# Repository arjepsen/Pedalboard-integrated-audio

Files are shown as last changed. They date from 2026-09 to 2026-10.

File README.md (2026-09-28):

# Open Guitar Processing Platform.

A custom Raspberry Pi Compute Module 5 guitar-processing platform with integrated low-latency audio and a separate ESP32-S3 user-interface board.

<p align="center">
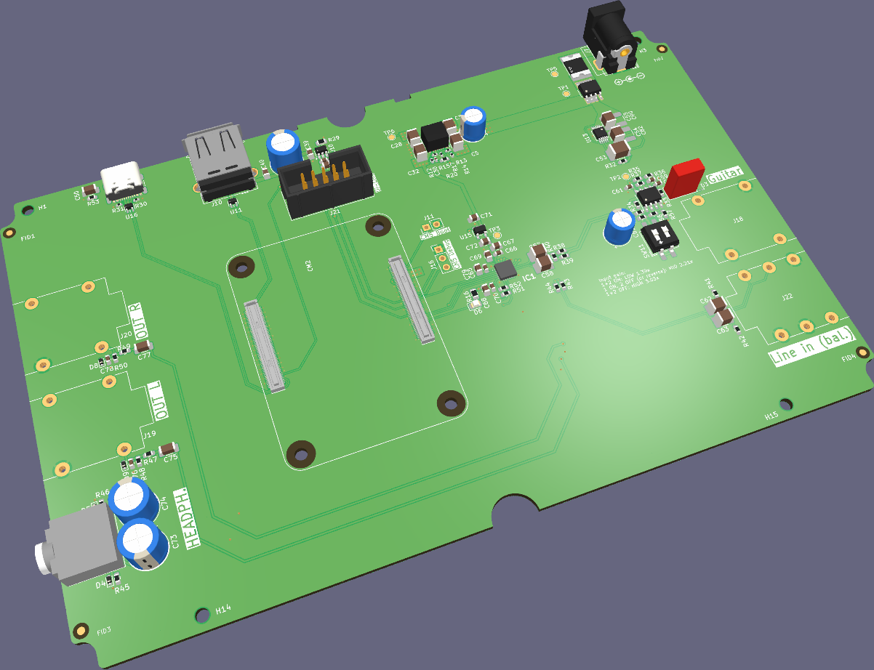
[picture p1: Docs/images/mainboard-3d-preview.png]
3D render of the mainboard
  
</p>

The project is derived from various other similar projects:
https://github.com/pedalboard
https://rerdavies.github.io/pipedal/
https://www.treefallsound.com/

The hardware has been substantially redesigned around an integrated TAC5212 audio codec, CM5, and a separate UI controller.

The primary software target is the **pi-Stomp / MOD** stack. **PiPedal** is intended as an alternative audio environment using the same hardware.

## Design goals

The main priorities are:

1. Low audio latency
2. High audio quality and low noise
3. Simple hardware where additional complexity provides no meaningful benefit
4. Clean separation of switching, digital, and sensitive analog circuitry
5. Practical manufacture and assembly through JLCPCB
6. Straightforward hand assembly of parts that are impractical or unnecessarily expensive to have assembled

## System architecture

The system is split between two PCBs.

### Mainboard

The mainboard contains the complete audio and compute system:

- Raspberry Pi Compute Module 5
- TAC5212 stereo audio codec
- OPA1656 high-impedance guitar input front end
- Balanced line input
- Dedicated stereo headphone output
- Stereo line/amp output
- TLVM13660 main 5 V power supply
- Low-noise analog power supply
- Codec power supplies
- USB service/recovery connection
- External USB host connection
- Power and UART connection to the UI board

The mainboard is a **four-layer PCB**.

### UI board

The physical controls and display are moved to a separate PCB based on:

- ESP32-S3-WROOM-1U-N8R2
- 3.5-inch SPI TFT display
- Four rotary encoders with push switches
- Four footswitch inputs
- One expression-pedal input
- Up to four indicator LEDs
- Optional chassis-wired MIDI input/output
- Local 3.3 V power supply

The UI board receives 5 V from the mainboard.

Communication between the CM5 and ESP32-S3 uses **UART**. There is no USB connection between the CM5 and UI controller.

The CM5 can also control ESP32-S3 reset and boot mode through the UI interconnect.

## Software architecture

### Primary environment

The primary target is the **pi-Stomp** software environment using:

- MOD-UI
- mod-host
- JACK
- LV2 plugins
- Neural Amp Modeler compatible processing

The intention is to retain the useful pi-Stomp interaction model while adapting it to the custom hardware.

### Alternative environment

**PiPedal** is intended to run as an alternative software environment on the same hardware.

MOD and PiPedal are not intended to operate simultaneously. The system will select which audio environment is active.

### Division of responsibilities

The **CM5** handles:

- Audio processing
- Plugin hosting
- Audio-engine control
- Presets and pedalboards
- System state
- Parameter state
- Communication with the TAC5212
- Communication with the UI controller

The **ESP32-S3** handles:

- Display rendering
- Rotary encoders
- Encoder push switches
- Footswitches
- Expression-pedal sampling
- Indicator LEDs
- Optional future MIDI handling
- Sending user commands to the CM5

The CM5 sends state changes to the ESP32-S3 rather than rendering the user interface (The display) itself.

## Audio architecture

The audio system is built around the **TI TAC5212** codec.

The normal operating point is:

- 48 kHz sample rate
- Stereo I2S
- 32-bit slots
- CM5 as I2S clock producer
- TAC5212 as clock consumer
- No separate audio master-clock oscillator
- Low-latency TAC5212 ADC and DAC filter modes

### Guitar input

Input channel 1 is intended for passive electric guitar pickups.

An **OPA1656** provides the high-impedance input stage and converts the guitar signal to the differential signal required by the TAC5212.

The design provides approximately 1 MΩ guitar input impedance and includes selectable input gain.

The codec input is AC-coupled.

### Line input

Input channel 2 provides a balanced line-level input.

It is AC-coupled into the second differential TAC5212 ADC input.

### Outputs

The system provides:

- Dedicated stereo headphone output
- Stereo unbalanced line/amp output

The TAC5212's output capabilities are used directly where practical in order to avoid unnecessary additional analog stages.

## Power architecture

The board accepts an external DC supply and generates the required system rails locally.

The main power path consists of:

1. Input protection
2. Reverse-polarity protection
3. TLVM13660 switching regulator
4. Main 5 V system rail

The 5 V rail supplies the CM5 and the downstream power systems.

Separate low-noise supplies are used where appropriate for sensitive analog and codec circuitry.

The analog guitar front end uses a quiet higher-voltage rail to provide adequate signal headroom.

The UI board receives 5 V from the mainboard and generates its own local 3.3 V supply.

Power-supply layout, switching-current loops, grounding, thermal performance, and separation from the analog signal path are treated as critical PCB-layout requirements.

## Mainboard / UI connection

The mainboard and UI board use a keyed 10-pin connection carrying:

| Signal | Function |
|---|---|
| +5V_UI | UI-board power |
| GND | Power/signal return |
| CM5_UART_TX | CM5 to ESP32-S3 data |
| CM5_UART_RX | ESP32-S3 to CM5 data |
| UI_RESET_REQ | ESP32-S3 reset request |
| UI_BOOT_REQ | ESP32-S3 boot-mode request |

Multiple 5 V and ground contacts are used in the connector.

The connection is intended to use a short ribbon cable between the two boards.

## USB

USB is kept separate from the UI-controller connection.

The CM5 provides a USB service connection for functions including:

- CM5 recovery / eMMC flashing
- Wired system access
- USB networking

An external USB host connection is also retained.

The ESP32-S3 UI board does not require a USB connection to the CM5.

## MIDI

MIDI is not required for the initial build.

The UI design is intended to preserve the possibility of adding MIDI later without requiring another mainboard revision.

If implemented, MIDI connectors will be chassis-mounted and wired to dedicated connection points on the UI board, rather than placing large DIN/TRS connectors directly on the PCB.

## Mechanical design

The system is intended for installation in an aluminium pedal enclosure.

The mainboard carries the CM5 and audio electronics.

The separate UI board sits beneath the top panel and carries the display, footswitches and rotary controls.

The design must provide sufficient cooling for the CM5. A heatsink and fan are expected, with enclosure ventilation provided as necessary.

The use of a separate UI PCB reduces congestion around the CM5 and allows the display and controls to be positioned according to the enclosure rather than the mainboard layout.

## PCB design

The mainboard uses a **four-layer stackup**.

Important layout priorities include:

- Continuous low-impedance ground
- Small switching-regulator current loops
- Correct TLVM13660 thermal layout
- Separation of the switching supply from sensitive audio circuitry
- Short codec analog paths
- Short local decoupling connections
- Controlled digital return paths
- Sensible separation of CM5, power, codec, and analog regions
- Appropriate USB differential routing
- Good thermal paths for the CM5 and power supply

The PCB is intended for manufacture and partial assembly by **JLCPCB**.

Where performance is equivalent, readily available and economical assembly parts are preferred. More expensive or manually fitted components are used where they provide a meaningful electrical, mechanical, or sourcing advantage.

## Current status

The project is currently in the mainboard PCB-layout stage.

The major mainboard architecture and audio topology have been established.

Current work includes:

- Component placement and floorplanning
- TLVM13660 routing and thermal-via implementation
- Power-distribution layout
- Analog/digital partitioning
- Ground and return-current planning
- Final verification of the mainboard before manufacture

The separate ESP32-S3 UI PCB will be designed after the mainboard architecture and mechanical relationship between the two boards are sufficiently settled.

Because this is intended as a one-off build rather than an iterative prototype programme, schematic and PCB decisions are being reviewed carefully before manufacture.

## Repository structure

The main KiCad project contains the CM5, audio, power, and external-connectivity hardware.

Important documentation is kept under `Docs/`, including:

- `project-status.md` — current project state
- `decisions.md` — established design decisions and their reasoning
- `design-notes.md` — detailed engineering notes
- `work-log.md` — chronological record of completed work
- `mainboard-ui-transition-plan.md` — transition from the former integrated controller to the separate ESP32-S3 UI architecture

The UI PCB is intended to remain part of this repository as a separate KiCad project so that the two boards, their interconnect, and their firmware interface can be versioned together.

## Project history

This project began as a modification of the Open Pedalboard hardware.

The design has since moved substantially beyond the original architecture, including:

- CM5-only compute platform
- Integrated TAC5212 audio codec
- Custom high-impedance guitar front end
- Revised audio outputs
- Revised power architecture
- Four-layer PCB
- TLVM13660 main supply
- Separate ESP32-S3 UI controller
- UART-based CM5/UI communication
- pi-Stomp/MOD as the primary software direction

The original Open Pedalboard project remains an important hardware and software reference.

## License

This project is derived from Open Pedalboard hardware.

See the repository license files and the original Open Pedalboard project for applicable licensing information.

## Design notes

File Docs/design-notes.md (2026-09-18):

# Design Notes

Last updated: 2026-09-17

## Audio architecture

- Selected codec: TAC5212IRGER, mounted directly on the mainboard.
- Primary use: guitar effects and NAM playback using Open Pedalboard or PiPedal software. Must be compatible with both.
- Input 1 is a high-impedance guitar input.
- Input 2 is an optional balanced line input.
- Both codec inputs are differential and AC-coupled.
- The CM connection uses I2S/PCM audio signals plus I2C control.
- Main audio operating point: 48 kHz sample rate, stereo I2S with 32-bit slots.
- CM5 is the I2S clock producer; TAC5212 follows BCLK and FSYNC and derives its internal clocks from that interface. No separate MCLK oscillator is required.
- Use the TAC5212 ultra-low-latency ADC and DAC filters for the main guitar path.

The TAC5212 combines the required stereo ADC and DAC. Its differential AC-coupled mode offers its best input performance, while programmable input impedance and full-scale settings allow the two analog paths to be adapted in software.

## Guitar input

The first OPA1656 half is a non-inverting guitar buffer with switchable gain. The second produces an equal, inverted signal for the differential ADC input. SW11 provides three useful gain settings without an invalid switch combination.

| Part | Purpose and reason |
|---|---|
| C56: 100 nF film, MKS2 footprint | Main input coupling capacitor; film construction suits the high-impedance signal node |
| C64: 100 nF C0G, 1206, DNP | Optional SMD alternative to C56; fit only one of the two capacitors |
| R33: 1 MΩ | Defines normal guitar input impedance and biases the buffer at 4 V |
| R34/R37: 1 kΩ | Equal values set the second amplifier to an inverting gain of -1 |
| R38/R39: 470 Ω and R40: 1 kΩ | Isolate the op-amp outputs and form a balanced divider that gives approximately 1x overall differential gain |
| R54/R56: 820 Ω, R55: 390 Ω, R57: 1 kΩ | Set the selectable non-inverting gains to approximately 1.39×, 2.21×, and 3.03× |
| SW11: EM-02-Q | Independently bypasses R54 and R56; either single-switch position gives the same middle gain |
| C57/C58: 4.7 µF Rubycon MF | Low-voltage-coefficient coupling into TAC5212 input 1 |
| D3: H5VUD5BB, DNP | Protection placeholder; not fitted until its capacitance and behavior are accepted |

C56 and R33 form a high-pass corner of about 1.6 Hz. The high-impedance node after C56 should be kept short and away from digital and switching signals.

The OPA1656 was chosen for its FET inputs, very low input bias current, low noise and distortion, and ability to operate from the 10 V single supply.

The selected TAC5212 range is 2 V RMS differential. Approximate guitar-jack clipping levels are 2.0 V peak on low gain, 1.3 V peak on middle gain, and 0.94 V peak on high gain.

## Line input

J22 is a balanced TRS line input. A TS plug remains usable because the ring is grounded by the plug.

| Part | Purpose and reason |
|---|---|
| R41/R42: 100 kΩ | Give both jack signal contacts a defined ground reference, provide balanced loading, and discharge the coupling capacitors |
| C62/C63: 4.7 µF Rubycon MF | AC-couple both balanced legs with a corner safely below the audio band |
| R43/R44: 7.5 kΩ | Provide equal series impedance, fault-current limiting, and line-level attenuation before the codec |

With the TAC5212 set to 5 kΩ input impedance, each 7.5 kΩ resistor gives approximately 0.4x voltage transfer. This corresponds to about 5 V RMS differential at J22 for the codec's 2 V RMS differential full scale.

The former JP4 connection from the jack switch to CM GPIO27 has been removed. The software does not use this automatic stereo-detection signal, and GPIO27 is intentionally unconnected.

## TAC5212 configuration assumptions

- Differential, AC-coupled input mode for both ADC channels.
- Main operating rate: 48 kHz.
- Stereo I2S with 32-bit slots; BCLK is 3.072 MHz at 48 kHz.
- CM5 produces BCLK and FSYNC; TAC5212 is the clock consumer.
- No dedicated audio master-clock oscillator is required.
- Use ultra-low-latency ADC and DAC filters for the main low-latency path.
- Set input-capacitor quick-charge timing to 25 ms for the 4.7 µF coupling capacitors.
- Use 5 kΩ per input pin, 2 V RMS differential full scale, and 0 dB initial codec gain on both ADC channels.
- Use the low-common-mode-variation AC-coupled setting for best noise performance.
- Final Linux register configuration and practical bring-up still require verification.

### TAC5212 local decoupling

- AVDD: C66 100 nF + C67 10 µF.
- IOVDD: C70 100 nF + C68 10 µF.
- DREG: C65 100 nF + C79 10 µF.
- VREF: C69 1 µF.
- C79 uses Samsung CL21A106KAYNNNE, 10 µF, 25 V, X5R, 0805, LCSC C15850.
- Place the DREG capacitors physically close to TAC5212 pin 1 during layout.

## Audio outputs

- Use the TAC5212 in four-channel single-ended output mode.
- Two outputs provide a dedicated stereo headphone connection on a 3.5 mm TRS jack.
- Two outputs provide left and right unbalanced line/amp signals on the existing 6.35 mm jacks.
- Configure the headphone pins for headphone drive and the 6.35 mm pins for line drive.
- Route the same stereo program to both output pairs using the TAC5212 playback mixer.
- Retain normal TS-cable compatibility; balanced outputs are not a present requirement.

This arrangement matches the primary desk-practice use without adding a separate headphone-amplifier IC. The single-ended line outputs give lower specified dynamic range than differential mode, but remain well above the expected system requirement. Final register settings and practical testing remain open.

## Power architecture

- Specify a regulated 12 V input with ±10% tolerance.
- Retain the 4 A / 15 V input PTC and FDS4435BZ reverse-polarity protection.
- Generate approximately 5.02 V with TLVM13660RDLR and its integrated inductor. R12 at 40.2 kΩ and R15 at 10 kΩ set the output. This rail supplies the CM and downstream regulators.
- Use AP22653W6-7 to switch and current-limit the external USB-A VBUS. R29 at 15 kΩ sets approximately 1.735 A typical. C39 and C40 at 10 µF plus C43 at 100 µF provide the recommended 120 µF output bank.
- Generate the general digital 3.3 V and `3V3_CODEC` analog rail with separate TPS7A2033PDBVR regulators.
- Keep C24 at 10 µF on the general 3.3 V regulator output.
- Generate the quiet 10 V guitar-front-end rail with LT3045EMSE#PBF. Use 4.7 µF on SET, 100 kΩ for 10 V, 10 µF at its input, and 22 µF at its output.
- Continue tracking total capacitance rail-by-rail together with regulator stability, soft-start, source impedance, and startup/inrush. Do not add local bulk capacitance without checking its effect on the whole rail.

The 10 V rail is retained because it gives the OPA1656 input path comfortable signal headroom. The approximately 5.02 V / 6 A supply provides useful CM5 and USB-current margin.

The general 3.3 V rail has been rechecked with the selected Waveshare displays. Each display is specified at about 46 mA maximum at 3.3 V, so the pair contributes about 92 mA. With the STM32 and the remaining small digital loads, the expected total is around 120 mA. The TPS7A2033 is rated for 300 mA, leaving comfortable current and thermal margin from the approximately 5.02 V input. C24 remains 10 µF because it is within the regulator's supported output-capacitance range and provides useful transient margin.

## Controller and displays

- U3 is an STM32G0B1CET6 in LQFP-48. It replaces the RP2040, its external QSPI flash, crystal, and associated support parts.
- Use the STM32's internal flash. No separate firmware flash is required.
- Use the internal HSI48 oscillator with USB clock recovery from the CM5 USB SOF signal. Firmware must enable CRS correctly; no external crystal is fitted.
- J15 and J17 connect to two Waveshare 2inch LCD Modules, SKU 17344. These are 2.0-inch 240×320 IPS displays using ST7789VW and 4-wire SPI.
- The modules are intended for straightforward screw/standoff mounting and use an 8-pin PH2.0 connector.
- J15 is the left display and J17 is the right display. Both use JST B8B-PH-K-S(LF)(SN) 8-pin, 2.0 mm vertical headers on the mainboard.
- The display connector pin order is BL, RESET, D/C, CS, SCK, MOSI, GND, 3V3. The shared signals are BL, RESET, D/C, SCK, and MOSI; each display has its own chip select.
- The Waveshare module includes its own 1 µF supply capacitor, so no extra local capacitor is fitted at J15/J17. The shared 3.3 V regulator retains C24 at 10 µF.
- The module contains the backlight switching transistor, so PA6 can drive both BL control inputs directly with PWM; an external backlight transistor is not required.
- Use DMA and small line/tile buffers rather than full framebuffers.
- Keep the display connectors on this controller/UI sheet. Their signals and power belong to the controller function, whereas the Connectivity sheet is for CM5 and external/service connections.
- Port the required controller behavior from the original Rust code to C/C++ while preserving its useful external USB-MIDI behavior and protocol.

### STM32 pin allocation

| Function | Pins |
|---|---|
| TFT shared SPI/control | PA5 SCK, PA7 MOSI, PA4 D/C, PB12 RESET, PA6 BL PWM |
| TFT chip selects | PB10 left, PB11 right |
| Addressable RGB LEDs | PA8 |
| Expression ADC inputs | PB0, PB1 |
| I2C | PB8 SCL, PB9 SDA |
| USB device | PA11 D−, PA12 D+ |
| SWD and reset | PA13 SWDIO, PA14 SWCLK, PF2 NRST |
| Optional DIN MIDI UART | PB6 TX, PB7 RX |
| Debug UART | PA9 TX, PA10 RX |
| Encoders | PA0–PA3, PB2, PB3 |
| Footswitches | PD0–PD3, PB4, PB5 |
| Boot/status | PC13 BOOT control, PB15 status LED |

Each expression input uses a 1 kΩ series resistor and 100 nF capacitor at the MCU. Retain the SWD/debug header and useful test points. The hierarchical `RGB_DATA` connection links U3 PA8 to the LED sheet.

### Controller EEPROM

Keep U12, the AT24CS01 EEPROM at I2C address `0x50`. The existing Open Pedalboard firmware stores active-preset state, per-preset switch state, and encoder values there. This avoids turning frequent runtime-state updates into STM32 internal-flash erase cycles. Its factory serial-number area is also useful for a stable board identity, even though the existing RP2040 firmware obtains its USB serial from the MCU flash ID instead.

## CM5-only connectivity

CM2 is now a Compute Module 5 using the `CM5IO:Raspberry-Pi-5-Compute-Module` footprint. The former FSUSB42 switch and USB2514B hub have been removed. CM5 exposes one USB 2.0 OTG connection and two native USB 3 host ports with USB 2.0 companion pairs, so the required USB 2.0 functions connect directly:

| CM5 connection | Board function |
|---|---|
| Legacy USB 2.0 OTG | USB-C CM5 service, recovery, and flashing |
| USB port 0 USB 2.0 pair | Internal STM32 USB-MIDI and firmware update |
| USB port 1 USB 2.0 pair | External USB-A host connector |

Leave the SuperSpeed pairs unused. The USB port 0 companion pair connects directly to U3; USB port 1 connects to the external USB-A connector; and the legacy USB 2.0 pair connects to the service USB-C connector. U11 and U16 provide low-capacitance data-line ESD protection.

The external USB-A power circuit follows Raspberry Pi's CM5 IO reference direction. CM5 pin 111 `VBUS_EN` directly drives the active-high AP22653 enable. R29 at 15 kΩ sets approximately 1.735 A typical current limit. C16 100 nF and C38 10 µF provide local input bypass, while C39, C40, and C43 total 120 µF on VBUS. The AP22653 also provides soft start, reverse-current protection, output discharge, current limiting, and thermal protection. Its `nFAULT` output may remain unconnected because the board does not presently need software fault reporting.

J9 is a self-powered USB-C device/service connection. R30 and R31 are 5.1 kΩ pull-downs on CC1 and CC2. Connector VBUS remains intentionally unconnected to prevent back-powering the board. SBU1 and SBU2 remain unconnected. CM5 `USB_OTG_ID` remains unconnected so its internal pull-up selects device operation, while J11 pulls `nRPIBOOT` low when recovery or eMMC flashing is required.

During PCB layout, place U11 and U16 immediately behind their connectors with short ground returns. Route each USB 2.0 pair over a continuous ground plane as a 90 Ω differential pair and avoid stubs. Place U10 input and output capacitors close to their corresponding pins.

## USB software compatibility

- Open Pedalboard uses the internal controller as a bidirectional class-compliant USB-MIDI device. It carries performance MIDI, controller configuration, state/feedback, and bootloader commands.
- Preserve the existing useful controller behaviour and custom configuration protocol in the STM32 implementation.
- Pedalboard OS currently identifies the RP2040 by its Raspberry Pi USB VID/PID and product name. The STM32 migration requires a new legitimate USB identity, stable serial number, updated udev matching, and updated bridge matching.
- The present firmware updater expects the RP2040 `RPI-RP2` mass-storage bootloader and a UF2 file. Replace this with an STM32G0B1 USB-DFU update path.
- PiPedal accepts the STM32 as a standard MIDI input and can bind it to presets, snapshots, plugin controls, hotspot control, shutdown, and reboot.
- PiPedal currently provides no MIDI output feedback. Basic operation needs no PiPedal changes, but dynamic preset names and state on the TFTs would require a future CM5 companion service.
- External USB-A remains useful for optional MIDI controllers, USB audio interfaces, and normal Linux USB peripherals.
- USB Ethernet gadget mode on the service USB-C port is a useful future option for web access, SSH, and file transfer, but is not required for the initial schematic.

## MIDI

- Preserve the original DIN MIDI input and output capability in the schematic, PCB, and STM32 pin allocation.
- The optional DIN MIDI group is marked DNP: J1–J4, J25, J26, L1–L4, R3–R5, D1, U2, C1, and C22.
- Keep the software routing options for DIN-to-USB and USB-to-DIN operation.
- Initial units can use `din_enabled: false`; the optional parts can be fitted later without revising the PCB.

The DNP state has been confirmed in the raw KiCad schematic and by exporting a BOM with DNP parts excluded.

## Manufacturing

- Primary manufacturer and assembler: JLCPCB.
- Basic parts are preferred when there is little or no disadvantage.
- Extended parts are acceptable when there is a clear benefit.
- Manual fitting is acceptable for a limited number of practical components.
- Use 0603 passives where practical.
- Fine-pitch and exposed-pad packages require suitable footprints, stencil design, and inspection.
- Write capacitor values with their unit, for example `100nF`, `1uF`, and `4.7uF`. Use compact resistor notation such as `27R`, `1k5`, and `100k`.
- Standard sourcing fields are `Manufacturer`, `Manufacturer part`, and `JLCPCB part`. Use KiCad's native footprint, datasheet, description, and DNP properties instead of duplicating them as custom fields.
- The electrical-component field audit is substantially complete. Finish exact purchasing choices for connectors and other hand-fitted mechanical parts before PCB/BOM release.
- Use a four-layer PCB with continuous reference planes. Do not attempt to preserve the original two-layer layout approach.
- Ignore gaps in reference numbering. References must be unique, not continuous.
- Remove the incomplete JLCPCB variant and create a new complete variant only after the default DNP state and schematic are frozen.

## Important project state

- `audio.kicad_sch` and `psu.kicad_sch` contain the current custom work.
- The guitar input, line input, TAC5212 support, digital-audio connections, and selected output circuits are present in the schematic.
- TAC5212 DREG now has C65 100 nF plus C79 10 µF local decoupling.
- The updated power architecture is present in the schematic.
- The STM32 controller, both Waveshare display connectors, optional DIN MIDI circuit, and direct CM5 USB arrangement are present in the schematic.
- The general 3.3 V rail has been checked with the selected displays and the TPS7A2033 is retained.
- The electrical-component value and sourcing-field audit is substantially complete; remaining gaps mainly concern mechanical or hand-fitted parts.
- The PCB has not yet been updated for the integrated audio circuit.

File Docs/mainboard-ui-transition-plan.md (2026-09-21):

# Mainboard UI Transition Plan

> This is a manual KiCad checklist. It records agreed changes but does not authorize automatic schematic edits.

**Goal:** Keep the CM5, audio, power, and external connectivity on the mainboard while moving the physical user interface to a later ESP32-S3 UI board.

**Architecture:** The CM5 remains responsible for audio, MOD, PiPedal, and system state. A separate UI board will later contain the ESP32-S3, display, encoders, switches, expression input, LEDs, and optional MIDI interface. The mainboard supplies 5 V and communicates with the UI board over UART.

**Scope:** Mainboard schematic changes only. The UI-board schematic and PCB are deliberately deferred.

## Hardware changes in short form

- Remove the STM32 controller subsystem from the active mainboard design.
- Remove the mainboard display, controls, expression, MIDI, and LED-interface circuitry that will move to the UI board.
- Add one keyed 2x5 IDC connector for UI power, UART, reset, and boot control.
- Free the CM5 USB port currently assigned to the STM32.
- Keep the existing CM5 USB-C service port and use it for both recovery flashing and USB Ethernet networking.
- Keep Wi-Fi as an option, using the CM5 wireless version and an external antenna in the aluminium enclosure.
- Keep the TAC5212, guitar input, optional line input, audio outputs, CM5, and established power supplies.
- Do not remove U5 during the controller cleanup. It still powers TAC5212 IOVDD in the present design and requires a separate power-domain decision.

## Mainboard-to-UI connector

Use a keyed and shrouded 2.54 mm IDC system.

| Item | Selection |
|---|---|
| PCB header | Würth Elektronik 61201021621 |
| Cable socket | Würth Elektronik 61201023021, with strain relief |
| Cable | 10-conductor, 28 AWG ribbon cable, approximately 100 mm |
| Assembly | Header marked DNP for JLCPCB and fitted by hand |

Pin numbering must follow the connector datasheet and footprint pin-1 mark.

| Pin | Signal | Purpose |
|---:|---|---|
| 1 | `+5V_UI` | UI power, connected to mainboard `+5VP` |
| 2 | GND | Power return |
| 3 | `+5V_UI` | Second power contact, connected to mainboard `+5VP` |
| 4 | GND | Power return |
| 5 | `CM5_UART_TX` | CM5 to ESP32-S3 |
| 6 | GND | Signal return |
| 7 | `CM5_UART_RX` | ESP32-S3 to CM5 |
| 8 | GND | Signal return |
| 9 | `UI_RESET_REQ` | CM5 requests ESP32-S3 reset |
| 10 | `UI_BOOT_REQ` | CM5 requests ESP32-S3 download mode |

`UI_RESET_REQ` and `UI_BOOT_REQ` are active-high requests. The later UI board will use local MOSFETs and pull-down resistors to pull ESP32-S3 EN and GPIO0 low. This prevents the CM5 from directly driving ESP pins across different power states.

## Mainboard schematic steps

### 1. Preserve a known baseline

- [ ] Commit and push the current schematic before beginning the transition.
- [ ] Run ERC and record the starting warning count.
- [ ] Confirm that the current PCB has not yet been updated for the new controller or audio design.

### 2. Add the UI connector on the Connectivity page

- [ ] Place a generic `Conn_02x05_Odd_Even` symbol on `connect.kicad_sch`.
- [ ] Assign the verified Würth 61201021621 footprint or import Würth's official KiCad footprint.
- [ ] Set `Value` to `UI LINK 2x5`.
- [ ] Set `Manufacturer` to `Würth Elektronik`.
- [ ] Set `Manufacturer part` to `61201021621`.
- [ ] Leave `JLCPCB part` empty.
- [ ] Mark the connector DNP.
- [ ] Add the note `Hand-fit. Mates with 61201023021 IDC socket and 10-conductor 28 AWG ribbon cable.`
- [ ] Wire pins 1 and 3 to the mainboard `+5VP` rail.
- [ ] Wire pins 2, 4, 6, and 8 to GND.
- [ ] Wire pins 5, 7, 9, and 10 according to the table above.

The mainboard does not need another UI power regulator. The UI board will receive 5 V and provide its own local 3.3 V regulation and decoupling.

### 3. Connect the CM5 control signals

- [ ] Keep `CM5_UART_TX` on CM2 pin 55, GPIO14.
- [ ] Keep `CM5_UART_RX` on CM2 pin 51, GPIO15.
- [ ] Remove the no-connect flag from CM2 pin 46, GPIO22, and label it `UI_RESET_REQ`.
- [ ] Remove the no-connect flag from CM2 pin 47, GPIO23, and label it `UI_BOOT_REQ`.
- [ ] Retain J16 as the DNP CM5 UART debug header.
- [ ] Add a note that J16 must not be connected to another transmitting device while the UI board is attached.

No level shifter is required because the CM5 GPIO and ESP32-S3 UART use 3.3 V logic.

### 4. Remove the old mainboard controller blocks

- [ ] Remove the active `MIDI` hierarchical-sheet instance that points to `pico.kicad_sch`.
- [ ] Remove the active `LEDs` hierarchical-sheet instance that points to `leds.kicad_sch`.
- [ ] Remove their obsolete hierarchical pins and connections from the root schematic, including `RGB_DATA`.
- [ ] Confirm that U3 STM32G0B1, U12 EEPROM, J12 SWD, J15/J17 displays, local switches, encoders, expression inputs, and MIDI circuits are no longer in the active mainboard hierarchy.
- [ ] Confirm that U1, C80, R7, R10, and J28 from the LED interface are no longer in the active mainboard hierarchy.
- [ ] Keep `pico.kicad_sch` and `leds.kicad_sch` as temporary reference files until the later UI project is created. Do not copy their old circuits blindly into the ESP32-S3 design.

### 5. Free the CM5 USB port previously used by STM32

- [ ] Remove the `USB_STM32_P` and `USB_STM32_N` labels and wiring.
- [ ] Add no-connect flags to CM2 pin 134, `USB3-0-DP`, and pin 136, `USB3-0-DM`.
- [ ] Leave the unused SuperSpeed signals for that port unconnected as they are now.

This USB port remains spare. The UI board uses UART, not USB.

### 6. Retain and relabel the CM5 service USB-C function

No electrical change is required around J9.

- [ ] Keep J9 D+ and D− connected to CM5 USB2 through U16.
- [ ] Keep R30 and R31 at 5.1 kΩ on CC1 and CC2.
- [ ] Keep J9 VBUS unconnected from the mainboard power rails.
- [ ] Keep CM2 pin 101, `USB_OTG_ID`, unconnected for device operation.
- [ ] Keep J11 pulling `nRPIBOOT` low for CM5 recovery and eMMC flashing.
- [ ] Update the J9 note to `Self-powered CM5 USB 2.0 service port for rpiboot flashing, USB Ethernet, and SSH. VBUS intentionally unconnected.`

Normal boot will allow USB Ethernet gadget networking. Booting with J11 fitted will instead enter CM5 recovery mode.

### 7. Recheck the power budget after removing STM32

- [ ] Keep the TLVM13660 5 V supply and its present component values.
- [ ] Reserve up to 1 A at 5 V for the complete UI board through the two power contacts.
- [ ] Include CM5 peak demand up to 2.5 A and the external USB-A limit of approximately 1.74 A in the total 5 V calculation.
- [ ] Confirm that expected codec, regulator, fan, and UI loads stay within the practical thermal capability of the 6 A supply and four-layer PCB layout.
- [ ] Do not remove U5 or change TAC5212 IOVDD during this controller transition. Review that power domain separately.

### 8. Record the Wi-Fi arrangement

- [ ] Use a wireless CM5 variant if Wi-Fi is wanted.
- [ ] Keep physical access to the CM5 U.FL connector.
- [ ] Reserve a possible enclosure position for the official Raspberry Pi external antenna kit.
- [ ] Do not add RF traces or an antenna connector to the mainboard schematic.

The external antenna is optional hardware. USB Ethernet through J9 remains the dependable wired control connection.

### 9. Verify before moving to PCB work

- [ ] Run ERC and resolve new errors caused by removed sheets or labels.
- [ ] Confirm that `USB_STM32_P`, `USB_STM32_N`, and `RGB_DATA` no longer appear in the active schematic.
- [ ] Confirm that GPIO22 and GPIO23 connect only to their corresponding UI request nets.
- [ ] Confirm that all ten UI connector pins match the agreed table.
- [ ] Confirm that the UI connector is DNP and has the correct manufacturer fields.
- [ ] Confirm that J9 VBUS and CM5 `USB_OTG_ID` remain intentionally unconnected.
- [ ] Commit and push the completed mainboard schematic transition.

## Deferred UI-board work

The later UI project will contain:

- ESP32-S3-WROOM-1U-N8R2 and its local 3.3 V supply.
- Display connector and display power control.
- Encoders, footswitch inputs, one expression input, and LEDs.
- Optional chassis-wired MIDI input and output circuitry.
- Local ESP32-S3 reset and boot buttons.
- MOSFET interfaces for `UI_RESET_REQ` and `UI_BOOT_REQ`.
- The matching 2x5 Würth connector, also hand-fitted and DNP for JLCPCB.

The UI schematic can wait until its display and mechanical layout are settled. Its board outline, display window, encoder positions, switch wiring, and cable exit must still be established before the mainboard PCB placement is frozen.

## Repository recommendation

Keep the UI PCB in this repository as a separate KiCad project, for example under `ui-board/`. The two PCBs share a cable pinout, enclosure, firmware interface, and release version, so one repository makes mismatches less likely. A separate GitHub repository would only be useful if the UI board were intended to become an independent reusable product.

## Decisions still separate from this plan

- Final display/module selection and its mechanical arrangement.
- Final UI-board 3.3 V regulator and display backlight power circuit.
- Whether TAC5212 IOVDD remains on U5 or later moves to a CM5-related power domain.
- Final enclosure antenna location and cooling arrangement.

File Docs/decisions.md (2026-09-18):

# Decisions

Last updated: 2026-09-17

## Confirmed

| Decision | Reason |
|---|---|
| Integrate the sound card on the mainboard | Remove the separate sound-card header and reduce the number of boards |
| Use the TAC5212 | Combines a high-performance stereo ADC and DAC, supports differential inputs and outputs, and provides programmable analog settings in one codec |
| Run the main audio path at 48 kHz | Matches the intended Open Pedalboard/PiPedal/NAM operating point without doubling DSP load for a negligible codec-latency improvement |
| Use CM5 as I2S clock producer and TAC5212 as clock consumer | CM5 supplies BCLK and FSYNC; TAC5212 can derive its internal clocks from BCLK, so no separate MCLK oscillator is required |
| Use stereo I2S with 32-bit slots | At 48 kHz this gives a 3.072 MHz BCLK and a conventional Linux audio interface |
| Use TAC5212 ultra-low-latency ADC/DAC filters | Minimizes codec conversion delay while retaining suitable audio-band performance |
| Set TAC5212 input-capacitor quick charge to 25 ms | The 4.7 µF input coupling capacitors need substantially longer settling than the default intended for smaller capacitors |
| Fit C65 100 nF plus C79 10 µF on TAC5212 DREG | Matches TI's local DREG decoupling requirement; C79 uses the same proven 10 µF part as other codec bulk decoupling |
| Use input 1 for guitar | A normal passive guitar needs a much higher input impedance than the codec provides directly |
| Use input 2 as a balanced line input | Adds a useful optional input without another active buffer stage |
| Use differential, AC-coupled codec inputs | This is the TAC5212 configuration intended for best dynamic-range performance |
| Use one clean 10 V analog rail | A negative rail adds complexity without a demonstrated audio benefit |
| Bias the OPA1656 at 4 V | Provides suitable input and output headroom from the 10 V single supply |
| Use OPA1656 for the guitar front end | Its FET inputs suit a 1 MΩ guitar input, while its low noise and distortion suit audio; one half buffers and the other creates the inverted signal |
| Use 100 nF for C56 | With R33 at 1 MΩ, the input high-pass corner is about 1.6 Hz, safely below the audio band |
| Keep C64 as a DNP C0G alternative to C56 | Provides an SMD assembly option without fitting two capacitors in parallel |
| Use Rubycon 16MF475KB23225 for C57/C58 and C62/C63 | The 4.7 µF non-polar polymer capacitors have low voltage dependence and suit low-distortion codec coupling |
| Use Basic 1% driver resistors | Premium 0.1% thin-film parts offer no meaningful system benefit here |
| Use a two-switch three-level guitar gain selector | SW11 independently bypasses two 820 Ω feedback sections, giving approximately 1.39×, 2.21×, and 3.03× gain with no invalid switch combination |
| Remove `audio_in_stereo` and JP4 | The original GPIO27 jack-detection idea is unused by the published Open Pedalboard software |
| Use four single-ended TAC5212 outputs | Allows simultaneous stereo headphones and stereo line outputs without another amplifier IC |
| Add a dedicated 3.5 mm stereo headphone output | Headphone practice is a primary use case; the TAC5212 provides a genuine headphone-driver mode |
| Keep two unbalanced 6.35 mm line/amp outputs | Preserves the original practical output use with ordinary TS cables while keeping the circuit simple |
| Replace RP2040 with STM32G0B1CET6, LQFP-48 | The two TFTs make the extra I/O and routing margin preferable to the 32-pin option |
| Use two Waveshare 2inch LCD Modules, SKU 17344 | 2.0-inch 240×320 IPS ST7789VW modules provide good image quality, screw mounting, a simple 8-pin PH2.0 connection, and keep the selected SPI display architecture |
| Use JST PH 8-pin mainboard connectors for both displays | Gives each removable display a simple matching cable connection; J15 is left and J17 is right |
| Omit extra display-connector decoupling capacitors | Each Waveshare module already has local 1 µF supply decoupling; the regulator output retains C24 at 10 µF |
| Keep TPS7A2033PDBVR for the general 3.3 V rail | Two Waveshare displays are specified at about 46 mA maximum each; with the STM32 and remaining small loads the rail has comfortable current and thermal margin below the regulator's 300 mA rating |
| Keep C24 at 10 µF on the digital TPS7A2033 output | The value is within the regulator's allowed output-capacitance range and provides useful transient margin |
| Track total rail capacitance and startup/inrush as the design changes | Local decoupling must be considered together with regulator stability, soft-start, source impedance, and whole-rail startup current rather than in isolation |
| Omit the STM32 external crystal | STM32G0B1 provides HSI48 with USB SOF clock recovery; the remaining controls, displays, LEDs, and MIDI do not justify the extra crystal parts |
| Drive display `BL` directly from STM32 PA6 | The Waveshare module contains the backlight switching transistor; PA6 carries only the PWM control signal |
| Keep the display connectors on the controller/MIDI sheet | Schematic pages are grouped by function, and the TFT bus and controls belong with the STM32 rather than CM5 external connectivity |
| Keep the AT24CS01 EEPROM | Existing controller software stores frequently changing preset, toggle, cycle, and encoder state in its 128 bytes at I2C address 0x50 to avoid internal-flash wear |
| Target C/C++ controller firmware | Port the required behavior rather than continuing the original Rust firmware |
| Specify a regulated 12 V input, ±10% | Provides suitable margin for the 10 V analog regulator without unnecessary converter stress |
| Use TLVM13660RDLR for the 5 V rail | The integrated-inductor 6 A module reduces external parts and layout risk while retaining suitable 12 V input and CM5 load margin |
| Set the main 5 V rail to approximately 5.02 V | R12 at 40.2 kΩ and R15 at 10 kΩ provide a small margin above nominal 5 V while staying close to the CM5 reference level |
| Keep AP22653W6-7 for external USB power | It is used by Raspberry Pi's CM5 IO reference design and provides soft start, reverse-current protection, output discharge, and controlled USB VBUS; 15 kΩ sets approximately 1.735 A typical |
| Use separate TPS7A2033 regulators for digital 3.3 V and codec analog 3.3 V | Keeps codec analog power isolated without an excessive component count |
| Keep LT3045 for the 10 V analog rail | Its low noise is useful for the guitar front end, and hand assembly is acceptable here |
| Make the redesigned mainboard CM5-only | Current Open Pedalboard software targets CM5, PiPedal supports the Pi 5 platform, and CM5 provides enough native USB ports to simplify the carrier |
| Use CM5 native USB ports instead of the hub/mux arrangement | Dedicate separate USB 2.0 pairs to service/flashing, the internal STM32, and external USB-A; leave SuperSpeed pairs unused |
| Replace CM4-specific symbols and net names with CM5 versions | The redesigned board no longer supports CM4, so its schematic and documentation should describe the actual target rather than retain misleading compatibility names |
| Preserve the Open Pedalboard controller behaviour on STM32 | Keep class-compliant bidirectional USB-MIDI and the useful existing MIDI/configuration protocol while replacing RP2040-specific hardware code |
| Keep optional DIN MIDI hardware, initially DNP | The software already supports DIN-to-USB and USB-to-DIN routing; retaining footprints allows the feature to be added later without paying for unused parts now |
| Target JLCPCB production | Prefer economical assembly choices while allowing justified premium or hand-fitted parts |
| Use a four-layer mainboard | Continuous ground and power planes improve switching-current return paths, codec grounding, USB routing, and first-build reliability |
| Recreate manufacturing variants only after design freeze | The current partial JLCPCB variant contains inconsistent overrides; the normal schematic DNP state remains the design source of truth until a new complete variant is made |
| Keep existing reference designators | Missing numbers such as C10 are harmless; preserving references avoids unnecessary schematic, PCB, and documentation churn |

## Preferences

| Preference | Guidance |
|---|---|
| Prefer JLCPCB Basic parts | Use them when performance and reliability are effectively unchanged |
| Pay more when justified | Audio quality, reliability, or availability can justify a better part |
| Allow limited manual assembly | Suitable for practical parts that can be fitted with the available microscope, soldering station, and heatbed |
| Keep documentation concise | Record actual design choices and reasoning, not incidental parts that happen to be available |

## Undecided

| Question | Current position |
|---|---|
| Guitar-input protection | D3 is currently DNP; choose protection that does not significantly load or distort the high-impedance input |
| Remaining mechanical-part metadata | Electrical passives and active parts are substantially audited; exact connectors and other hand-fitted mechanical parts still need final purchasing choices |
| Which parts should be hand-fitted? | Decide from JLCPCB availability, assembly cost, and soldering difficulty |
| USB practical validation | The schematic topology and parts are confirmed; verify differential routing, connector-side ESD placement, shield bonding, and service/recovery operation on the finished PCB |
| STM32 USB identity and updating | Select a legitimate VID/PID and replace the RP2040 UF2 update path with STM32 USB DFU |
| USB-C networking after boot | USB Ethernet gadget mode would provide convenient web-interface and SSH access, but is a future software choice rather than a present hardware requirement |

## Selected parts

| Use | Part | JLCPCB status when last checked |
|---|---|---|
| 4 V divider | R35: 15 kΩ, UNI-ROYAL 0603WAF1502T5E, C22809 | Basic |
| 4 V divider | R36: 10 kΩ, UNI-ROYAL 0603WAF1002T5E, C25804 | Basic |
| Guitar driver | R34/R37/R40: 1 kΩ, 0603WAF1001T5E, C21190 | Basic |
| Guitar driver | R38/R39: 470 Ω, 0603WAF4700T5E, C23179 | Basic |
| Codec coupling | C57/C58/C62/C63: Rubycon 16MF475KB23225, C50394238 | Extended; stock must be rechecked |
| Codec DREG bulk decoupling | C79: 10 µF, Samsung CL21A106KAYNNNE, C15850 | Basic when last checked |
| 5 V buck module | U6: TLVM13660RDLR, C5219281 | Integrated-inductor 6 A module; assembly status must be rechecked |
| External USB switch | AP22653W6-7, 15 kΩ current-setting resistor, C2158037 | Extended; matches the CM5 IO reference circuit |
| 3.3 V regulators | TPS7A2033PDBVR | Status must be rechecked |
| Digital 3.3 V output capacitor | C24: 10 µF, Samsung CL21A106KAYNNNE, C15850 | Basic when last checked |
| 10 V analog regulator | LT3045EMSE#PBF | Intended for manual assembly |
| Controller MCU | STM32G0B1CET6, C5270267 | Extended; exact stock and sourcing must be rechecked |
| Display modules | 2 × Waveshare 2inch LCD Module, SKU 17344 | External module; not JLCPCB assembled |
| Display connectors | J15/J17: JST B8B-PH-K-S(LF)(SN), C157974 | Extended when last checked |
| STM32 bulk capacitor | C17: CL21A475KAQNNNE, C1779 | Basic when last checked |
| MIDI protection diode | D1: 1N4148W, C81598 | Basic when last checked; MIDI option is initially DNP |

Basic/Extended classification and stock are time-dependent and must be checked again before ordering.

## Working rule

The assistant must not change design or project files without explicit approval. The normal workflow is discussion and instructions, followed by changes made by the project owner. Documentation-only edits also require approval.

## Schematic value and field convention

- Capacitor `Value` fields include the capacitance unit: `100nF`, `1uF`, and `4.7uF`. Resistors use compact engineering notation such as `27R`, `1k5`, and `100k`.
- Use `Manufacturer`, `Manufacturer part`, and `JLCPCB part` as the standard sourcing fields.
- Use the native KiCad footprint, datasheet, description, and DNP properties instead of duplicating them as new custom fields.
- Generic passives should still receive exact manufacturer and JLCPCB parts once a production choice is made.

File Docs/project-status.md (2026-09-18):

# Project Status

Last updated: 2026-09-17

## Goal

Adapt the Open Pedalboard mainboard into a practical, CM5-only integrated guitar-effects and NAM player that can use Open Pedalboard and PiPedal software and is suitable for JLCPCB production.

## Current direction

| Area | Status | Direction |
|---|---|---|
| Audio codec | Confirmed | Mount a TAC5212 directly on the mainboard |
| Guitar input | Circuit complete | High-impedance OPA1656 buffer and differential ADC drive; final input-protection choice remains open |
| Line input | Circuit complete | Balanced TRS, AC-coupled into TAC5212 input 2 |
| Codec integration | Schematic substantially complete | 48 kHz stereo I2S, 5 kΩ inputs, 2 V RMS differential range, 0 dB initial gain, ultra-low-latency filters, and 25 ms input-cap quick charge; final Linux implementation remains |
| Audio outputs | Circuit drawn | Dedicated 3.5 mm stereo headphones plus two unbalanced 6.35 mm line/amp outputs |
| Power supply | Circuit updated | 12 V input, approximately 5.02 V / 6 A TLVM13660 module, separate 3.3 V rails, and quiet 10 V analog rail; TPS7A2033 retained for the general 3.3 V rail |
| Controller | Schematic replaced | STM32G0B1CET6 with two Waveshare 2inch LCD Modules, direct CM5 USB, SWD, controls, and optional MIDI |
| Compute module | Confirmed | The redesigned board supports CM5 only |
| Connectivity | Circuit confirmed | CM5 native USB pairs directly serve service USB-C, internal STM32, and external USB-A; AP22653 host power and both ESD circuits have been checked |
| External MIDI | Schematic drawn, initially DNP | DIN MIDI footprints, interface circuit, STM32 pins, and software direction are retained for future fitting |
| Manufacturing | Confirmed | Target JLCPCB assembly on a four-layer board; rebuild variants only after design freeze |

## Completed schematic work

- Selected the TAC5212 stereo codec.
- Added an OPA1656-based guitar input with a 4 V bias supply.
- Added SW11 for three guitar gain settings: approximately 1.39×, 2.21×, and 3.03×.
- Set C56 to the 100 nF design value.
- Added C64 as a DNP 100 nF C0G/1206 alternative footprint for C56.
- Completed the balanced line input using C62/C63, R41/R42, and R43/R44.
- Removed JP4 and the unused `audio_in_stereo` detection net; CM GPIO27 is intentionally unconnected.
- Added TAC5212 power, local decoupling, I2C/I2S connections, headphone outputs, and line/amp outputs.
- Added C79 10 µF on TAC5212 DREG in parallel with C65 100 nF, matching the local DREG decoupling requirement.
- Selected 48 kHz stereo I2S with 32-bit slots, CM5 as clock producer, TAC5212 as clock consumer, and no separate MCLK oscillator.
- Selected TAC5212 ultra-low-latency ADC/DAC filters for the primary guitar path.
- Selected 25 ms input-capacitor quick charge for the 4.7 µF codec input coupling capacitors.
- Reworked the main power tree around TLVM13660RDLR, AP22653W6-7, TPS7A2033, and LT3045.
- Selected STM32G0B1CET6 in LQFP-48 for the controller redesign.
- Replaced the original display choice with two Waveshare 2inch LCD Modules, SKU 17344, using ST7789VW over shared SPI.
- Replaced the display connections with JST PH 8-pin mainboard headers, J15 left and J17 right, with separate chip selects.
- Removed redundant display-connector capacitors; the Waveshare modules provide local 1 µF decoupling and C24 remains 10 µF at the digital 3.3 V regulator output.
- Rechecked the general 3.3 V rail: the two selected displays contribute about 92 mA maximum combined, and the TPS7A2033 has comfortable current and thermal margin for the expected total load.
- Confirmed that the redesigned mainboard is CM5-only and will use native CM5 USB ports rather than preserving the CM4 hub/mux architecture.
- Confirmed the external USB-A power circuit against the AP22653 datasheet and Raspberry Pi CM5 IO reference: active-high `VBUS_EN`, 15 kΩ current programming, and 120 µF output capacitance.
- Confirmed that the STM32 controller will preserve the original bidirectional USB-MIDI behaviour and optional DIN MIDI routing.
- Replaced the RP2040, external QSPI flash, crystal, and RP2040 support circuit with STM32G0B1CET6.
- Selected crystal-less STM32 operation: HSI48 with USB SOF clock recovery for USB and the internal clock for the remaining controller functions.
- Added filtered expression inputs, a five-pin SWD header, debug-UART test points, reset/boot buttons, and a status LED.
- Confirmed that all optional external-MIDI connectors and avoidable interface parts are marked DNP for the initial build.
- Retained the AT24CS01 EEPROM because the controller software uses it for frequently updated runtime state.

## Current project state

- The custom audio work exists in the schematic only.
- The PCB still represents the original mainboard and plug-in sound card.
- The integrated audio circuitry is substantially drawn but still needs final review, ERC cleanup, and PCB implementation.
- D3 is DNP while the guitar-input protection choice is reviewed.
- The controller sheet now contains the STM32 subsystem and no longer contains the RP2040 or external QSPI flash as active circuitry.
- J15 and J17 are the left/right Waveshare display connectors using JST PH 8-pin headers.
- The CM5 symbol and footprint are present as CM2, and the former USB hub and mux have been removed.
- CM5 native USB pairs now serve service USB-C, the internal STM32, and external USB-A directly.
- The hierarchical `RGB_DATA` connection now links STM32 PA8 to the LEDs sheet.
- The general 3.3 V rail has been checked and the existing TPS7A2033 plus C24 = 10 µF are retained.
- Rail capacitance and startup/inrush must continue to be checked as local bulk capacitors are added or changed.
- The electrical-component value and sourcing-field audit is substantially complete. Remaining choices mainly concern connectors and other hand-fitted mechanical parts.
- TAC5212 clocking and analog input settings are settled. Final Linux register implementation and practical bring-up remain open.
- The existing partial JLCPCB variant must not be used for production. Remove it and rebuild a complete variant after design freeze.
- Gaps in reference numbering are intentionally left unchanged.
- STM32 migration will also require a new USB identity, updated Pedalboard OS matching, and USB-DFU firmware-update support instead of RP2040 UF2 flashing.

## Next sequence

1. Complete the power-startup, inrush, and thermal review.
2. Freeze default DNP states, then create production variants and the manufacturing BOM.
3. Rework the PCB as a four-layer design for the integrated audio, CM5, STM32, display connectors, and updated power circuits.
4. Validate USB service/recovery operation and host-port load behavior on the assembled board.

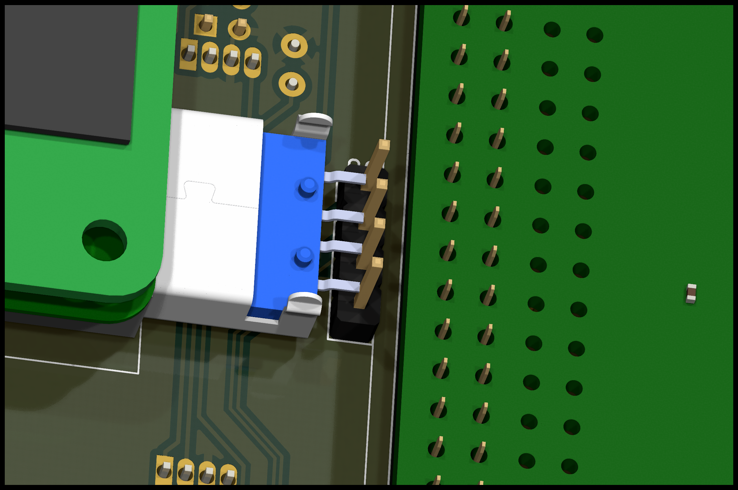
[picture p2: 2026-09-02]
img/cm4-usb.png

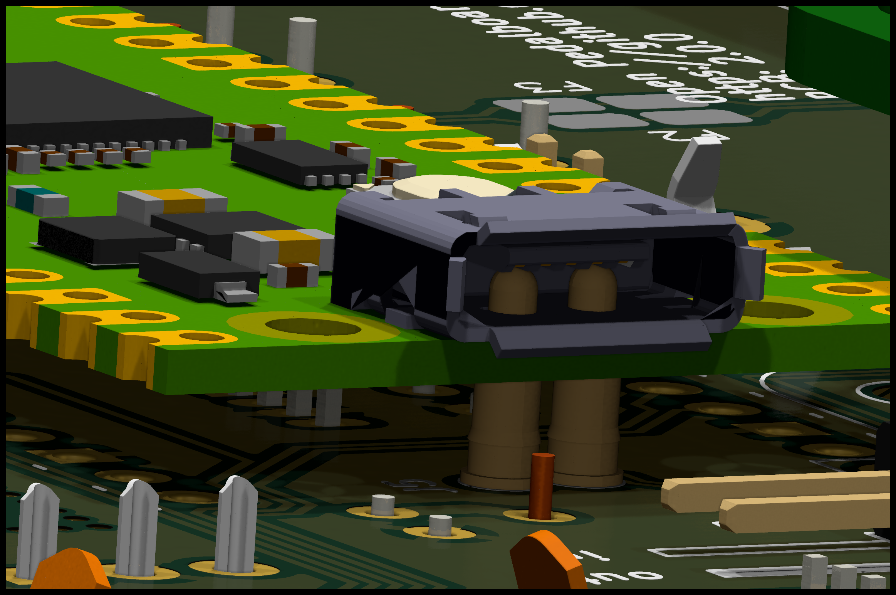
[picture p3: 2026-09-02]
img/pico-usb.png

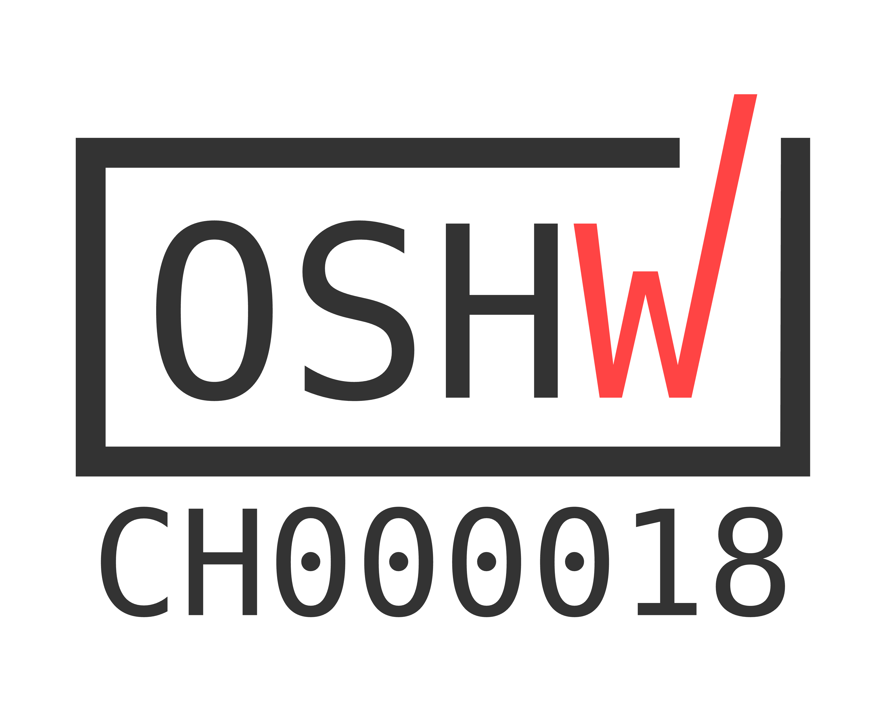
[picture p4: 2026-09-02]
img/certification-mark-CH000018-stacked.png

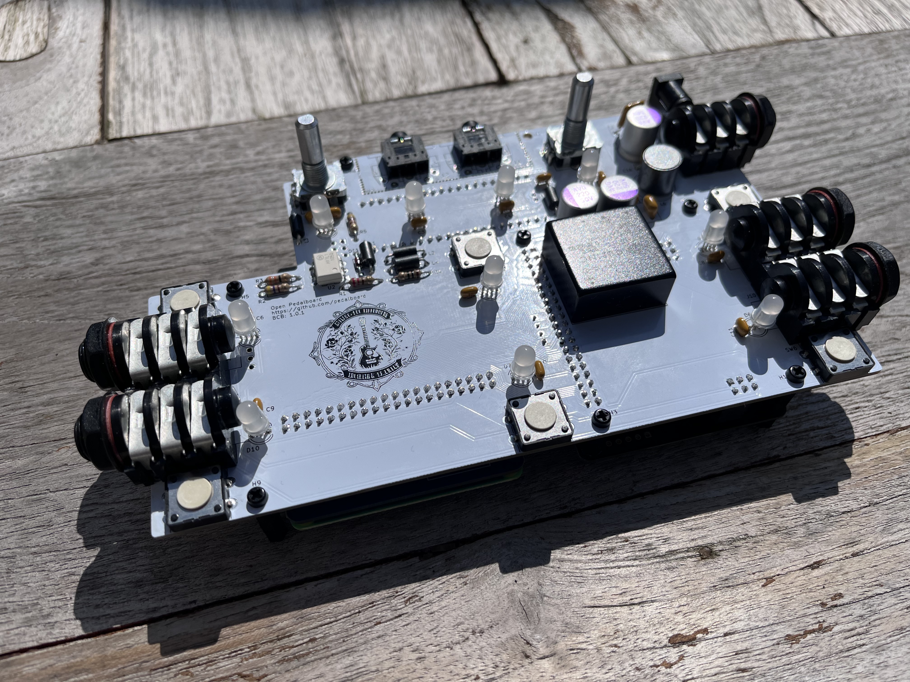
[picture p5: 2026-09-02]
img/prototype.jpeg

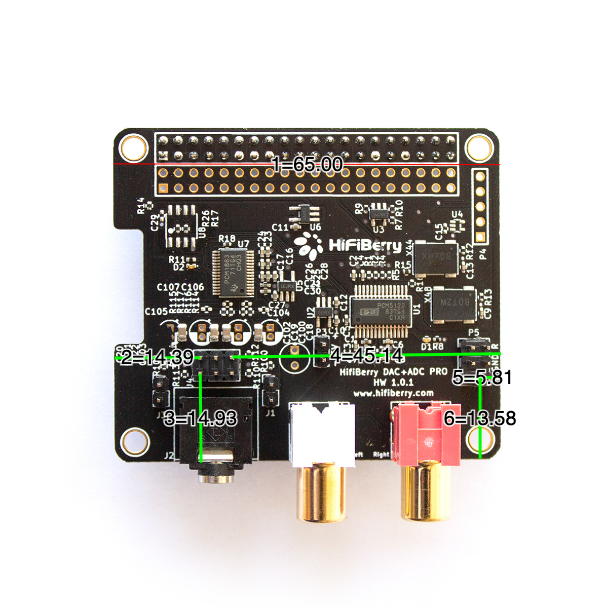
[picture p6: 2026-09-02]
img/dac-adc.png

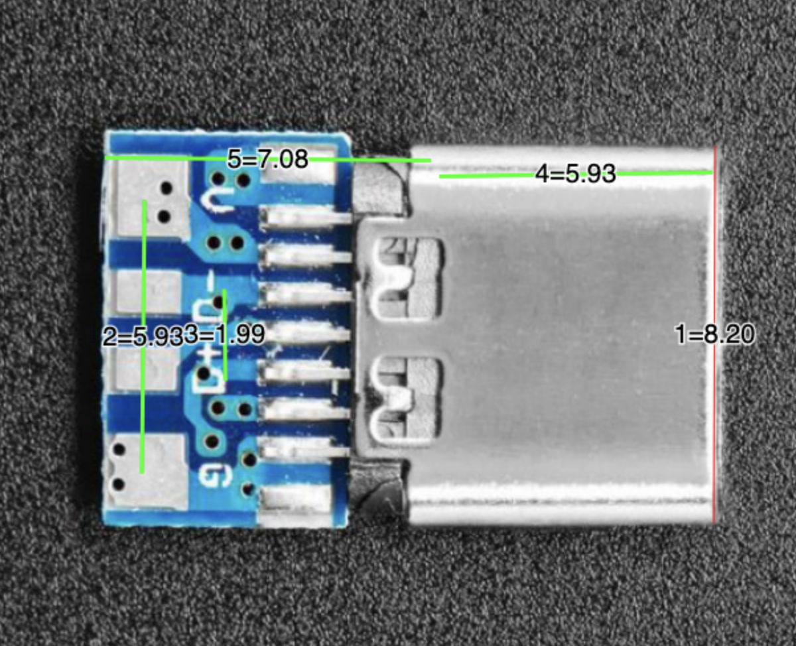
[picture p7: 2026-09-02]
img/usb-c.png

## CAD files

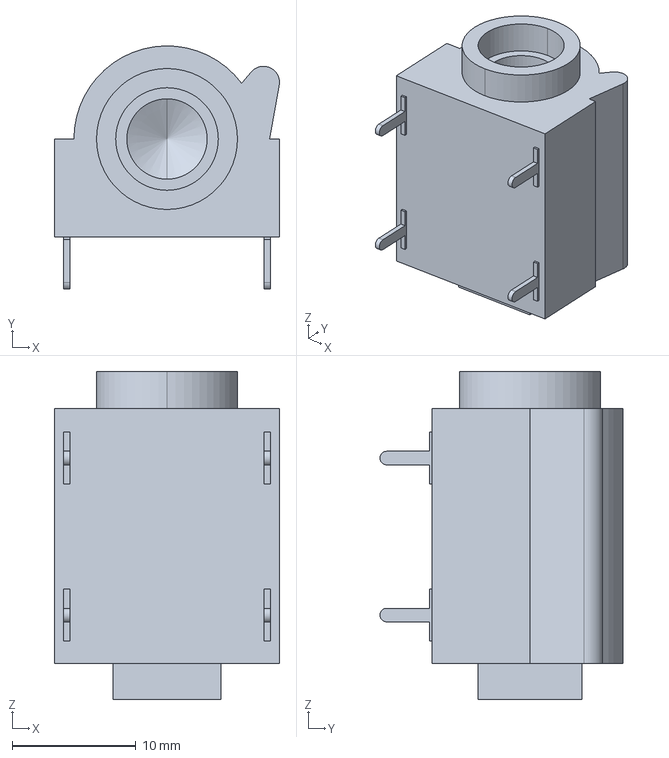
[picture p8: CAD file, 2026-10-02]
3d-models/D-NMJ4HCD2.stp
18.2 x 19.7 x 26.5 mm

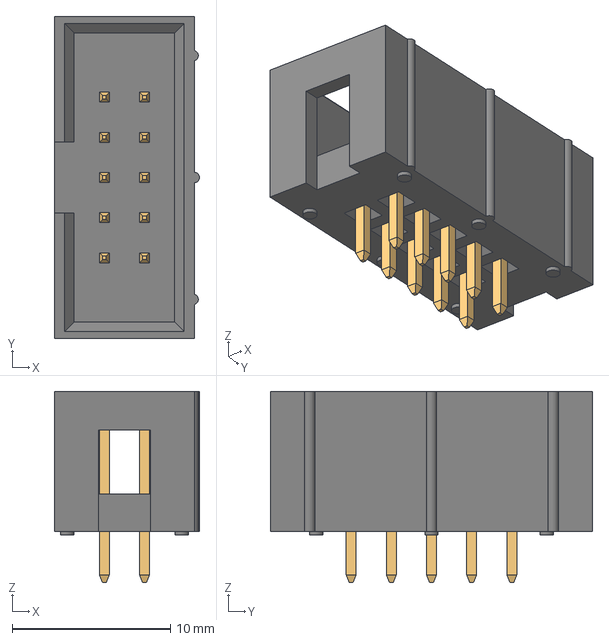
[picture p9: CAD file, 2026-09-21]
3d-models/J_Wurth_WR-BHD_61201021621.step
9.18 x 20.4 x 12.1 mm

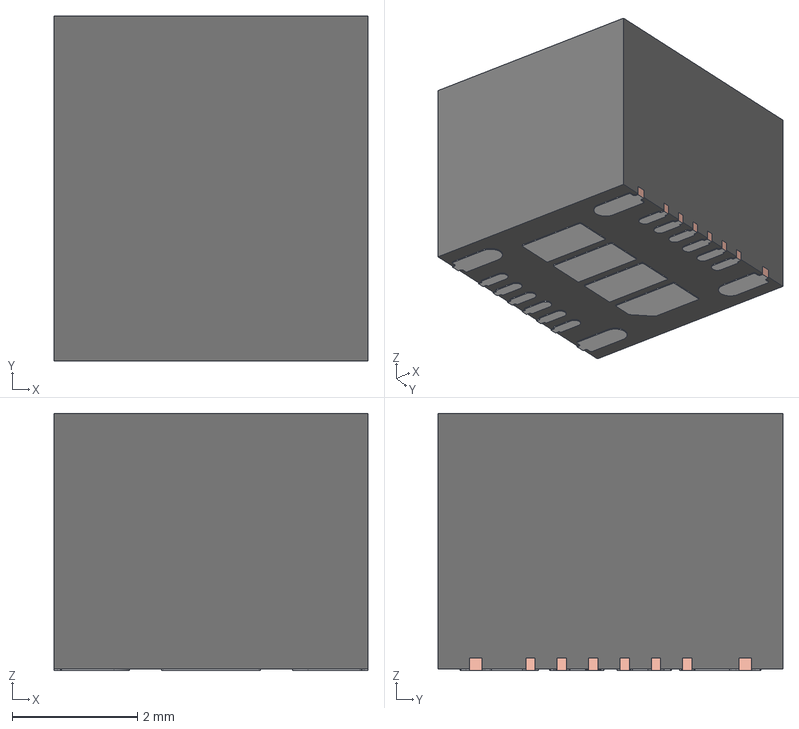
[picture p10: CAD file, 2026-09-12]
3d-models/RDL0020A.stp
5.00 x 5.50 x 4.10 mm
FRAME
MOLD

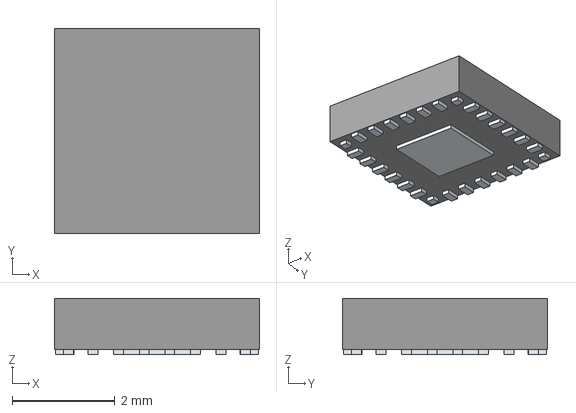
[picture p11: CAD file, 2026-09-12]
3d-models/TAC5212IRGER.stp
4.00 x 4.00 x 1.10 mm
Pins

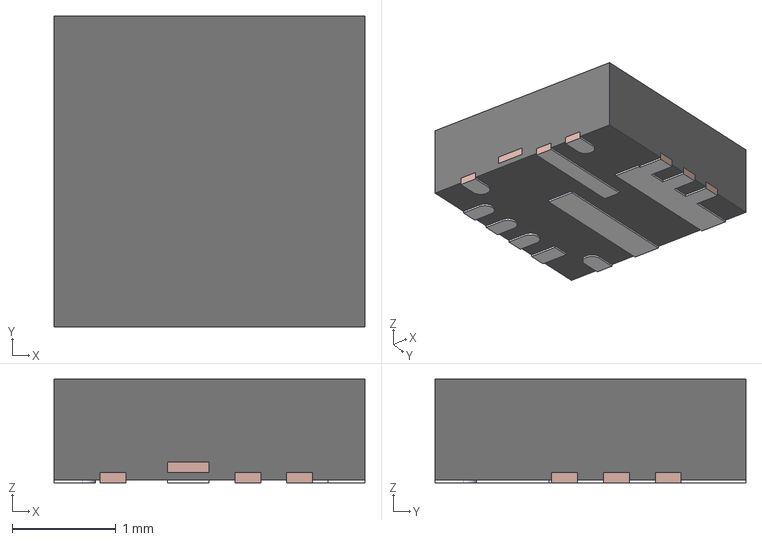
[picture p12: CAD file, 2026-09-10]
3d-models/RPA0010A.stp
3.00 x 3.00 x 1.00 mm
FRAME
MOLD

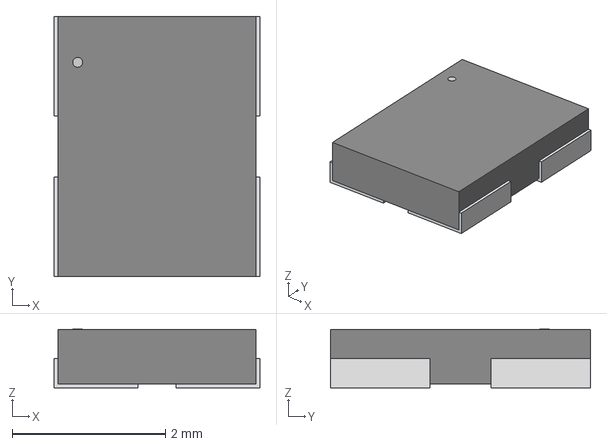
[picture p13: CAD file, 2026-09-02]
3d-models/ABM8-272-T3_ABR.step
2.69 x 3.40 x 0.765 mm

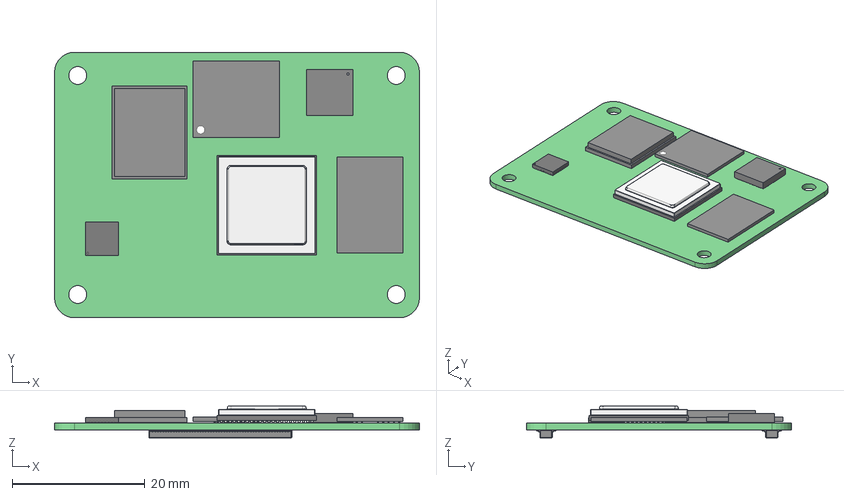
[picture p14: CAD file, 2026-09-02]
3d-models/cm-min.step
55.0 x 40.0 x 4.78 mm
PCB
BROADCOM_BCM2711
CONNDF40C-100DP-04V
CONNDF40C-100DP-04V (1)
MAXLINEAR_MXL7704-R
QFN-48_7X7X0P9
RM0_FOOTPRINT_V2
SAMSUNG_KLM4G1YE4C-B00X
SDRAM-LPDDR4-X32-D2-BGA200

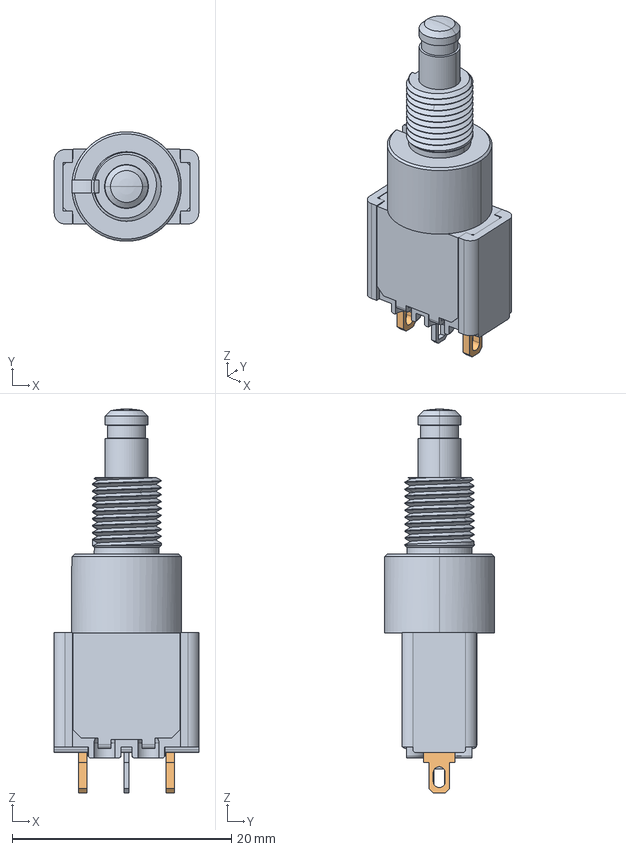
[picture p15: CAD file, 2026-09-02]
3d-models/APEM_8632A_aligned.step
13.2 x 10.0 x 35.1 mm

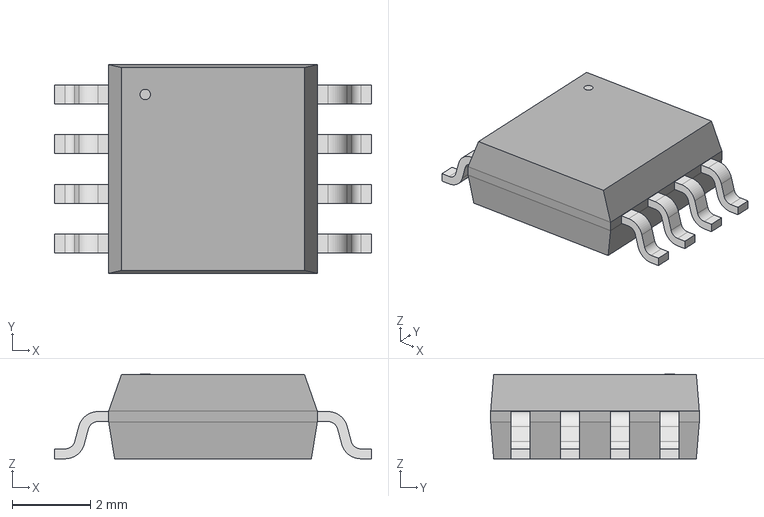
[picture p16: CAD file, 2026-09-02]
3d-models/SOIC_128JVSIQ_WIN.step
8.10 x 5.33 x 2.16 mm

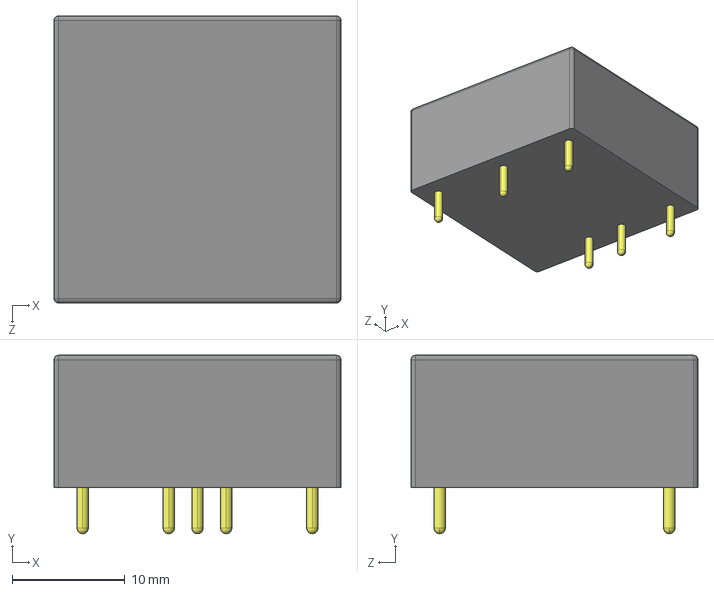
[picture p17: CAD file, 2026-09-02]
3d-models/PDQE15-Q24-S5-D.step
25.4 x 15.8 x 25.4 mm

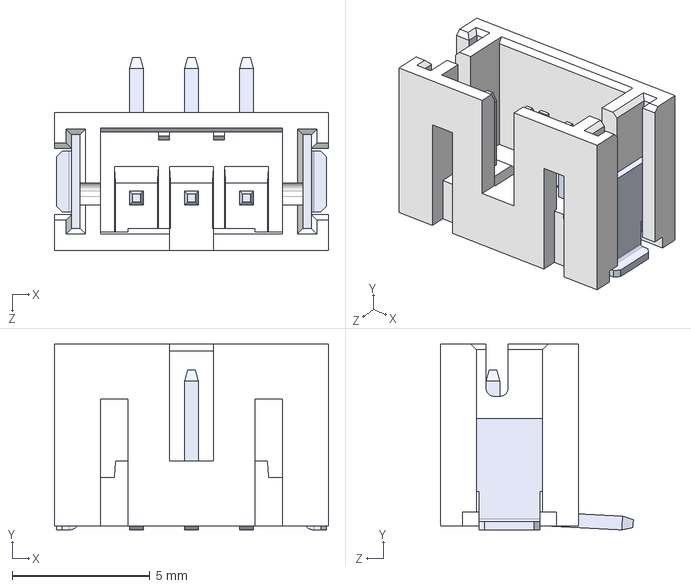
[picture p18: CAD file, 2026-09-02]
3d-models/B3B-PH-SM4-TB(LF)(SN)--3DModel-STEP-269445.STEP
9.95 x 6.75 x 7.00 mm

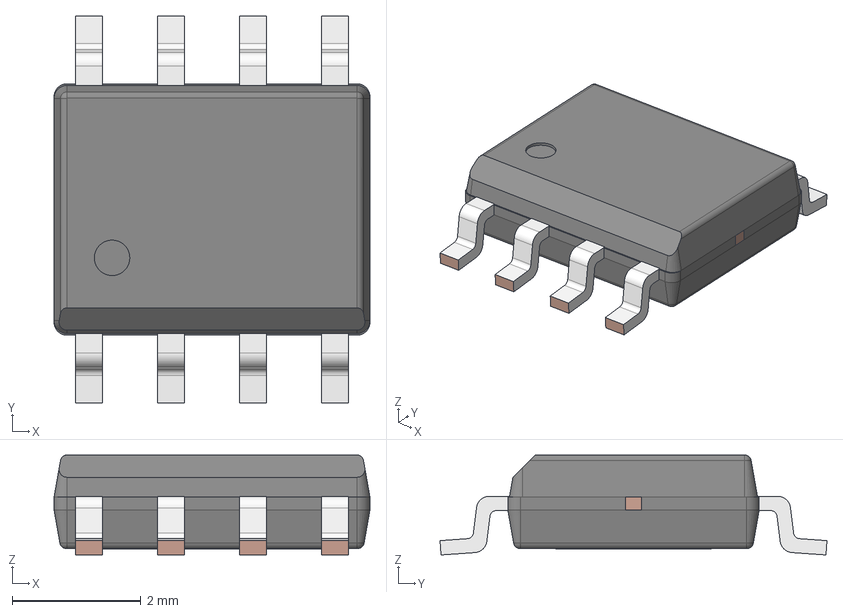
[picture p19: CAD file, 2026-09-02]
3d-models/SO-8EP.STP
4.90 x 6.00 x 1.55 mm
CPD
LDF - outer lead
LDF - 8L-EP

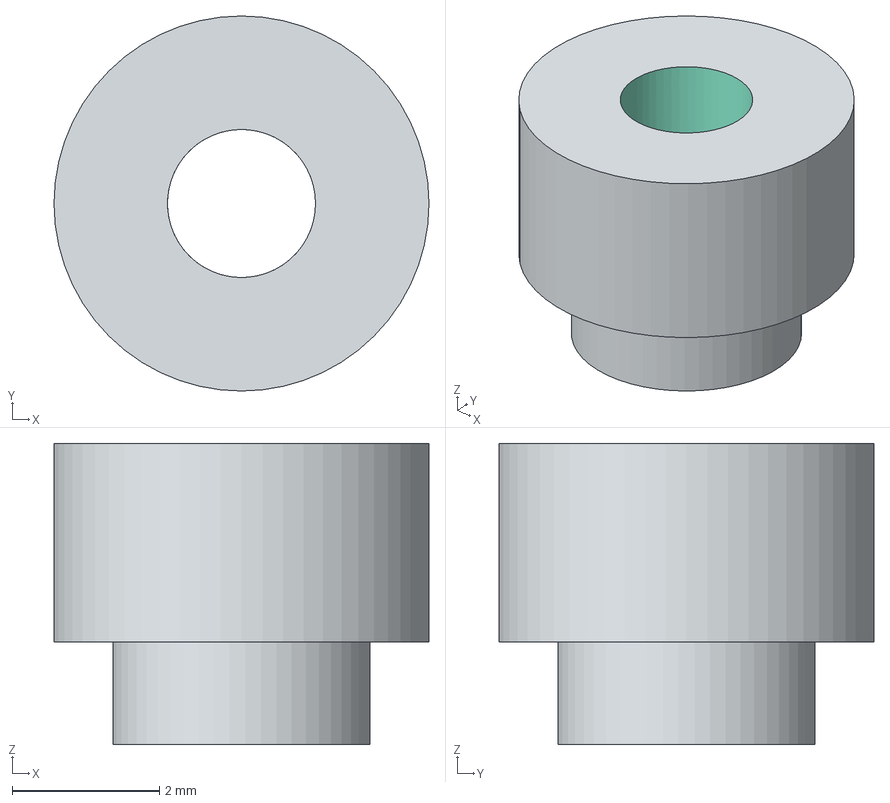
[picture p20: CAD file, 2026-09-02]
3d-models/spacer.stp
5.10 x 5.10 x 4.10 mm

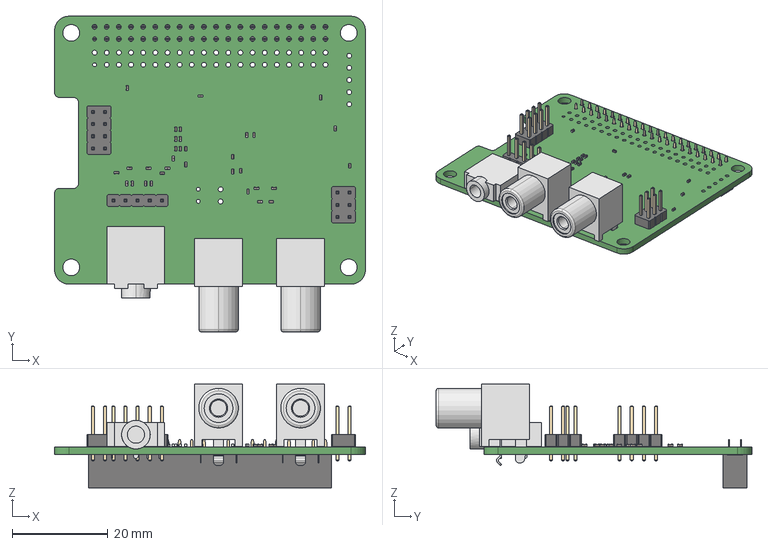
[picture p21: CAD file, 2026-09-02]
3d-models/hifiberry-dac-plus-adc-1.2.step
65.0 x 66.0 x 21.6 mm

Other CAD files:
3d-models/3-D NMJ6HCD2.stp
3d-models/DF40C-100DS.stp
3d-models/CM4-NANO-A.step
3d-models/EC11E-05SW.STEP
3d-models/10103594-0001LF--3DModel-STEP-269445.STEP
3d-models/694106301002 (rev1).stp
3d-models/B4B-PH-SM4-TB (LF)(SN).STEP
3d-models/USB1061-GF-L-A.stp
3d-models/USB_Micro-B_Wuerth_614105150721.step
3d-models/WE-tact-button.stp
3d-models/mill-max-0906-2-15-20-75-14-11-0.step
3d-models/pedalboard-led-ring-3D.step
3d-models/pedalboard-soundcard-3D.step

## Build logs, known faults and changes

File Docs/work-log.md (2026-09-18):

# Work Log

## 2026-09-17 - Input settings, metadata, and manufacturing direction confirmed

- Confirmed TAC5212 differential AC-coupled inputs at 5 kΩ per pin, 2 V RMS differential full scale, 0 dB initial codec gain, and 25 ms input-capacitor quick charge.
- Confirmed SW11 independently bypasses the two 820 Ω feedback sections and provides approximately 1.39×, 2.21×, and 3.03× guitar gain.
- Completed the main electrical-component metadata pass. Remaining gaps mainly concern mechanical or hand-fitted parts.
- Confirmed TLVM13660RDLR as the integrated-inductor 5 V regulator module.
- Selected a four-layer PCB for the integrated design.
- Agreed to remove the incomplete JLCPCB variant and recreate production variants only after design freeze.
- Agreed to retain existing reference designators; missing numbers are harmless.
- Restored the agreed capacitor-value convention using `uF` and `nF`.
- Confirmed AP22653W6-7 as the external USB-A power switch. The circuit matches Raspberry Pi's CM5 IO reference direction with active-high `VBUS_EN`, a 15 kΩ current-setting resistor, and 120 µF output capacitance.
- Corrected the documented USB current-limit target from 1.5 A to approximately 1.735 A typical.
- Confirmed the service USB-C CC pull-downs, data-line ESD parts, intentional unconnected VBUS, `nRPIBOOT` header, and device-role connection.

## 2026-09-11 - TAC5212 clocking, latency, and DREG decoupling confirmed

- Added C79, 10 µF, on TAC5212 DREG in parallel with C65 100 nF.
- Selected 48 kHz as the main system sample rate.
- Selected stereo I2S with 32-bit slots, giving 3.072 MHz BCLK at 48 kHz.
- Selected CM5 as I2S clock producer and TAC5212 as clock consumer; no separate MCLK oscillator is required.
- Selected TAC5212 ultra-low-latency ADC and DAC filters for the primary low-latency guitar path.
- Selected 25 ms input-capacitor quick charge for the 4.7 µF codec input coupling capacitors.
- Began tracking total capacitance rail-by-rail together with regulator stability, soft-start, source impedance, and startup/inrush rather than treating local decoupling independently.
- Left exact TAC5212 ADC input impedance/full-scale/gain settings as the next analog review item.

## 2026-09-11 - Waveshare displays and 3.3 V rail confirmed

- Replaced the HS20S010B display choice with two Waveshare 2inch LCD Modules, SKU 17344, using ST7789VW over the existing shared SPI architecture.
- Selected JST PH 8-pin vertical mainboard connectors, J15 for the left display and J17 for the right display.
- Confirmed separate left/right chip-select signals while sharing BL, reset, D/C, SCK, MOSI, power, and ground.
- Removed the redundant display-connector decoupling capacitors because each Waveshare module already includes local 1 µF supply decoupling.
- Rechecked the general 3.3 V rail with the actual display load: about 46 mA maximum per display, about 92 mA combined.
- Retained TPS7A2033PDBVR for the general 3.3 V rail; expected total load remains comfortably below its 300 mA rating with acceptable thermal margin.
- Retained C24 at 10 µF on the digital 3.3 V regulator output for transient margin.
- Added the Waveshare display, module schematic, and ST7789VW datasheets to the repository.

## 2026-09-11 - STM32 controller, TFT, and CM5 USB migration drawn

- Replaced the RP2040, external firmware flash, and crystal with U3, an STM32G0B1CET6.
- Selected crystal-less USB operation using HSI48 and CRS synchronized from the CM5 USB SOF signal.
- Added the controller pin allocation, expression-input filters, SWD/debug connections, and status/boot functions.
- Added two HS20S010B TFT connectors with shared SPI/control and separate chip selects.
- Confirmed from the module information that `BLK` is a logic input; both displays can be driven directly from PA6.
- Replaced the CM4-era USB hub and mux with direct CM5 USB connections for service USB-C, internal STM32, and external USB-A.
- Verified that the optional DIN MIDI group is marked DNP in both the KiCad source and an exported BOM.
- Retained the AT24CS01 EEPROM because the existing controller software writes changing preset, switch, and encoder state to it.
- Standardized the documented passive-value convention on `100n`, `1u`, `4.7u`, `1k5`, and similar forms without redundant unit letters.
- Verified that the hierarchical `RGB_DATA` connection links U3 PA8 to the LED sheet.
- Left the general 3.3 V capacity audit as the next power task.
- Added a later whole-project audit of component values and sourcing fields before PCB/BOM release.

## 2026-09-09 - USB software and MIDI direction reviewed

- Reviewed the maintained Open Pedalboard software and current PiPedal USB behaviour.
- Confirmed that Open Pedalboard should retain bidirectional class-compliant USB-MIDI and its useful controller configuration behaviour when moving to STM32.
- Identified the RP2040-specific USB identity and UF2 updater as software that must change for STM32 USB DFU.
- Confirmed that PiPedal can use the STM32 for incoming MIDI control without modification; dynamic display feedback would require a future companion service.
- Confirmed that optional DIN MIDI input/output will remain in the design but the connectors and avoidable interface parts will initially be DNP.
- Confirmed that the CM4 symbol, footprint, and CM4-specific net names must be replaced with a verified CM5 representation before USB rewiring.
- Selected CM5 representation and direct native USB routing as the next schematic work, before the STM32 replacement.

## 2026-09-09 - CM5-only scope confirmed

- Confirmed that the redesigned mainboard will support CM5 only.
- Selected separate native CM5 USB 2.0 connections for service/flashing, the internal STM32, and external USB-A.
- CM4 compatibility is no longer a design requirement.
- The saved schematic still contains the old hub and mux until the replacement circuit is fully verified.

## 2026-09-09 - Power and controller direction updated

- Reworked the power tree for a regulated 12 V input.
- Selected TPS56637RPAR for approximately 5.08 V / 6 A, with margin for CM5 and external USB loads.
- Retained AP22653W6-7 for current-limited external USB power.
- Selected separate TPS7A2033 regulators for digital 3.3 V and codec analog 3.3 V.
- Retained LT3045 for the quiet 10 V guitar-front-end rail.
- Confirmed STM32G0B1CET6 in LQFP-48 and two HS20S010B/ST7789V2 TFTs as the controller baseline.
- Traced the existing USB hub and mux functions and identified the CM5 native-USB simplification; no connectivity circuit was changed during that audit.

## 2026-09-03 - Output direction selected

- Confirmed that the TAC5212 provides configurable headphone drivers rather than only line-level outputs.
- Selected a dedicated 3.5 mm stereo headphone output as a primary feature.
- Retained two unbalanced 6.35 mm line/amp outputs for normal pedalboard use.
- Chose the TAC5212 four-channel single-ended mode so both output pairs can operate without another amplifier IC.
- Left output coupling, filtering, protection, jack detection, and software configuration for later design.

## 2026-09-03 - Input circuits and documentation reviewed

- Verified the guitar input and balanced line-input paths against the saved schematic.
- Confirmed C56 is designed as 100 nF; incidental substitute values are not design decisions.
- Recorded the component values and concise reasoning for both input paths.
- Traced the original `audio_in_stereo` net to a planned GPIO27 jack-detection function.
- Confirmed the published Open Pedalboard software does not use that signal.
- Removed JP4 and the `audio_in_stereo` labels; CM GPIO27 is intentionally unconnected.
- Identified the TAC5212 core supplies, digital interface, and output circuit as the next unfinished audio block.

## 2026-09-03 - Previous design handover reviewed

- Reconciled the earlier ChatGPT design record with the live KiCad files.
- Recorded the two-layer constraint, 10 V analog rail, 4 V bias, and OPA1656 topology.
- Recorded the 100 nF film design capacitor and Rubycon codec-coupling capacitors.
- Recorded the Basic 1% resistor decision and exact known JLCPCB parts.
- Recorded the C/C++ firmware direction and provisional STM32G0B1KET6 candidate.
- Flagged the DNP guitar-input protection device as an open choice.

## 2026-09-02 - Project orientation

- Identified `PedalBoard-integrated-audio` as the active project.
- Treated the other Open Pedalboard folders as reference material.
- Confirmed that TAC5212 and OPA1656 work is present in the audio schematic.
- Confirmed that the PCB still represents the original plug-in sound-card design.
- Confirmed that the RP2040 controller section has not yet been replaced.
- Recorded the JLCPCB and manual-assembly preferences.
- Created the project documentation structure.

## Logging format

Future entries should contain only:

- Conclusions reached
- Decisions changed
- Work actually completed
- Important open questions

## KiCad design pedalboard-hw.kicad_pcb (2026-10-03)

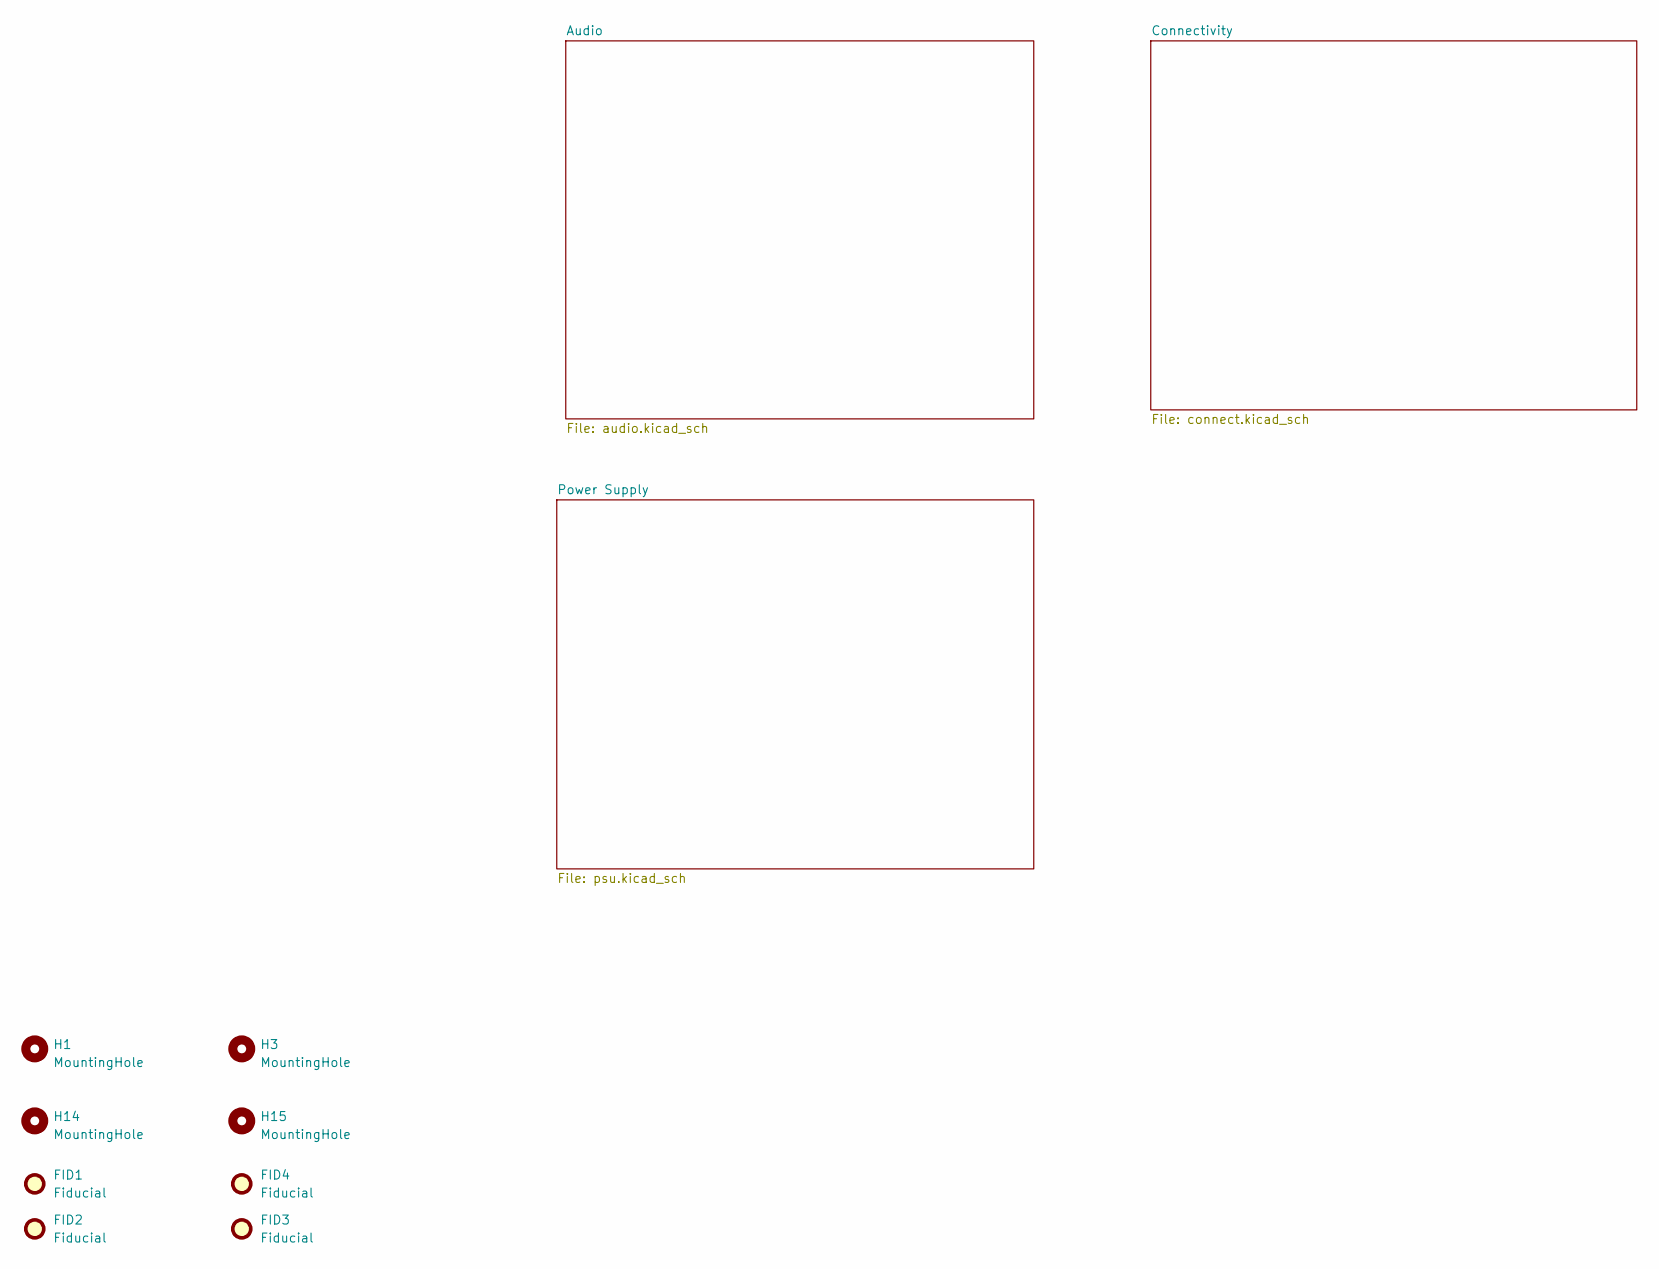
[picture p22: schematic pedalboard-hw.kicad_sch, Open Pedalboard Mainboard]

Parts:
FID1, FID2, FID3, FID4: Fiducial; Fiducial_1.5mm_Mask3mm
H1, H3, H14, H15: MountingHole; MountingHole_2.7mm_M2.5_DIN965

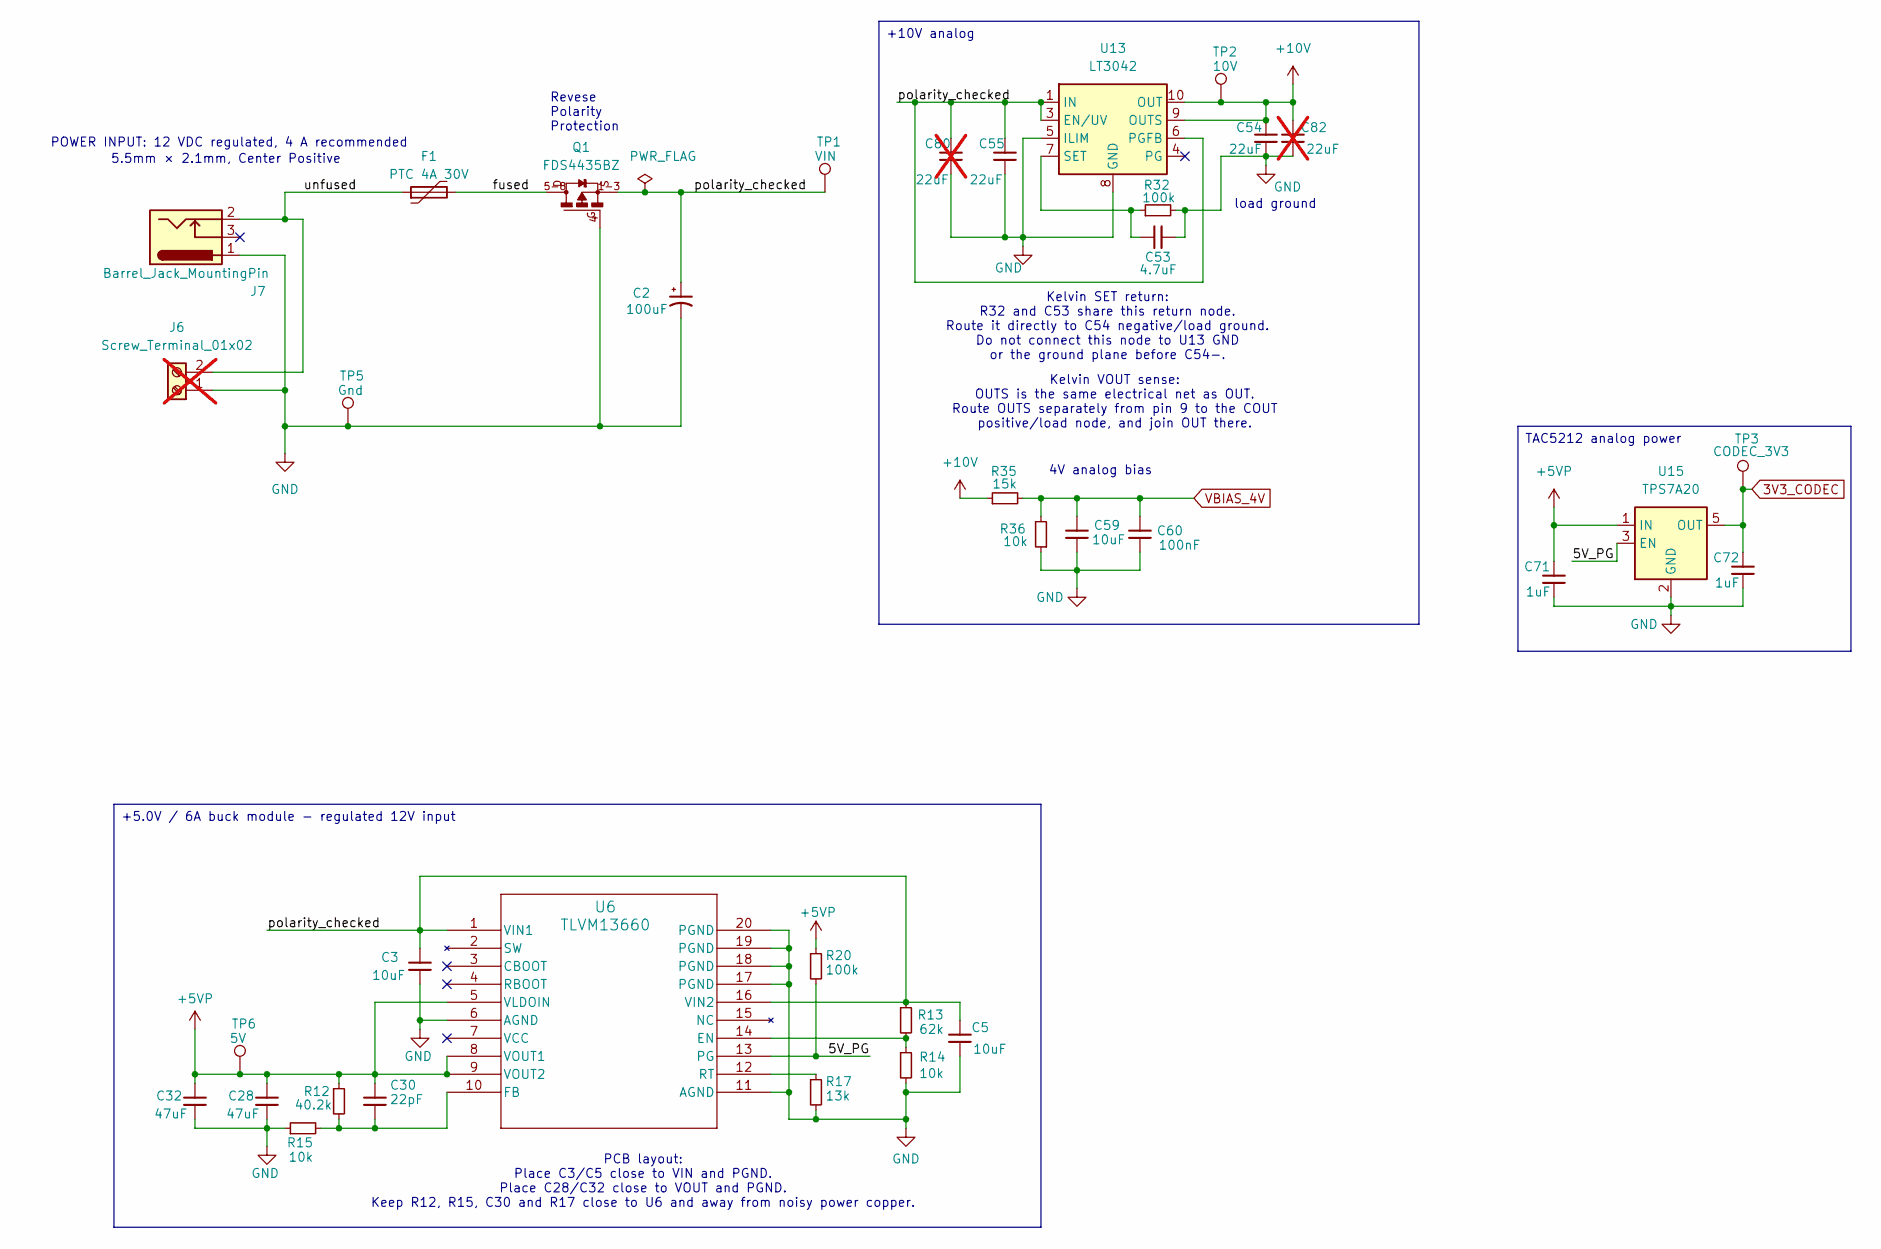
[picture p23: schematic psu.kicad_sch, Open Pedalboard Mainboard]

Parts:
C2: 100uF; CP_Radial_D6.3mm_P2.50mm; Manufacturer part NHG
C3, C5: 10uF; C_1210_3225Metric; Manufacturer part C3225X7R1H106KT000E; JLCPCB part C432929
C28, C32: 47uF; C_1210_3225Metric; Manufacturer part GRM32ER71A476ME15L; JLCPCB part C415541
C30: 22pF; C_0402_1005Metric; Manufacturer part 0402CG220J500NT; JLCPCB part C1555
C53: 4.7uF; C_1812_4532Metric; Manufacturer part 35MU475KC44532
C54, C55: 22uF; C_1210_3225Metric_Pad1.33x2.70mm_HandSolder; Manufacturer part CL32B226KAJNNNE; JLCPCB part C309062
C59: 10uF; C_0603_1608Metric; Manufacturer part CL10A106KP8NNNC; JLCPCB part C19702
C60: 100nF; C_0603_1608Metric; Manufacturer part CC0603KRX7R9BB104; JLCPCB part C14663
C71, C72: 1uF; C_0805_2012Metric; Manufacturer part CL21B105KBFNNNE; JLCPCB part C28323
C80, C82: 22uF; C_1210_3225Metric_Pad1.33x2.70mm_HandSolder; Manufacturer part CL32B226KAJNNNE; JLCPCB part C309062; not fitted
F1: PTC 4A 30V; Fuse_2920_7451Metric; Manufacturer part 2920L400/30GR; JLCPCB part C19078761
J6: Screw_Terminal_01x02; TerminalBlock_Phoenix_MKDS-1,5-2_1x02_P5.00mm_Horizontal; Manufacturer part 1715022; not fitted
J7: Barrel_Jack_MountingPin; BarrelJack_Wuerth_6941xx301002; Manufacturer part 694106301002
Q1: FDS4435BZ; SO08-E3; Manufacturer part FDS4435BZ
R12: 40.2k; R_0402_1005Metric; Manufacturer part 0402WGF4022TCE; JLCPCB part C25893
R13: 62k; R_0402_1005Metric; Manufacturer part 0402WGF6202TCE; JLCPCB part C37825
R14, R15: 10k; R_0402_1005Metric; Manufacturer part 0402WGF1002TCE; JLCPCB part C25744
R17: 13k; R_0402_1005Metric; Manufacturer part 0402WGF1302TCE; JLCPCB part C25754
R20, R32: 100k; R_0603_1608Metric; Manufacturer part 0603WAF1003T5E; JLCPCB part C25803
R35: 15k; R_0603_1608Metric; Manufacturer part 0603WAF1502T5E; JLCPCB part C22809
R36: 10k; R_0603_1608Metric; Manufacturer part 0603WAF1002T5E; JLCPCB part C25804
TP1: VIN; TestPoint_Pad_D1.5mm
TP2: 10V; TestPoint_Pad_D1.5mm
TP3: CODEC_3V3; TestPoint_Pad_D1.5mm
TP5: Gnd; TestPoint_Pad_D1.5mm
TP6: 5V; TestPoint_Pad_D1.5mm
U6: TLVM13660; B3QFN20_RDL_TEX; Manufacturer part TLVM13660RDLR; JLCPCB part C5219281
U13: LT3042; MSOP-10-1EP_3x3mm_P0.5mm_EP1.68x1.88mm; Manufacturer part LT3042EMSE#PBF; JLCPCB part C69847
U15: TPS7A20; SOT-23-5; Manufacturer part TPS7A2033PDBVR; JLCPCB part C2862740

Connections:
3V3_CODEC: C72.1, TP3.1 (1_1), U15.5 (OUT); also elsewhere on the board
+5VP: C28.1, C30.1, C32.1, C71.1, R12.1, R20.1, TP6.1 (1_1), U6.5 (VLDOIN), U6.8 (VOUT1), U6.9 (VOUT2), U15.1 (IN); also elsewhere on the board
+10V: C54.1, C82.1, R35.1, TP2.1 (1_1), U13.9 (OUTS), U13.10 (OUT); also elsewhere on the board
/Power Supply/5V_PG: R20.2, U6.13 (PG), U15.3 (EN)
/Power Supply/fused: F1.2, Q1.5-8
/Power Supply/polarity_checked: C2.1, C3.1, C5.1, C55.1, C80.1, Q1.1-3, R13.1, TP1.1 (1_1), U6.1 (VIN1), U6.16 (VIN2), U13.1 (IN), U13.2 (IN), U13.3 (EN/UV), U13.6 (PGFB)
/Power Supply/unfused: F1.1, J6.2, J7.2
GND: C2.2, C3.2, C5.2, C28.2, C32.2, C53.2, C54.2, C55.2, C59.2, C60.2, C71.2, C72.2, C80.2, C82.2, J6.1, J7.1, Q1.4, R14.2, R15.1, R17.2, R32.2, R36.1, TP5.1 (1_1), U6.6 (AGND), U6.11 (AGND), U6.17 (PGND), U6.18 (PGND), U6.19 (PGND), U6.20 (PGND), U13.5 (ILIM), U13.8 (GND), U13.11 (GND), U15.2 (GND); also elsewhere on the board
unnamed: R13.2, R14.1, U6.14 (EN)
unnamed: C30.2, R12.2, R15.2, U6.10 (FB)
unnamed: R17.1, U6.12 (RT)
unnamed: C53.1, R32.1, U13.7 (SET)
VBIAS_4V: C59.1, C60.1, R35.2, R36.2; also elsewhere on the board

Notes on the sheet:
load ground
Kelvin SET return: R32 and C53 share this return node. Route it directly to C54 negative/load ground. Do not connect this node to U13 GND or the ground plane before C54−.
5.5mm × 2.1mm, Center Positive
POWER INPUT: 12 VDC regulated, 4 A recommended
Revese Polarity Protection
PCB layout: Place C3/C5 close to VIN and PGND. Place C28/C32 close to VOUT and PGND. Keep R12, R15, C30 and R17 close to U6 and away from noisy power copper.
Kelvin VOUT sense: OUTS is the same electrical net as OUT. Route OUTS separately from pin 9 to the COUT positive/load node, and join OUT there.
4V analog bias
TAC5212 analog power
+5.0V / 6A buck module - regulated 12V input
+10V analog

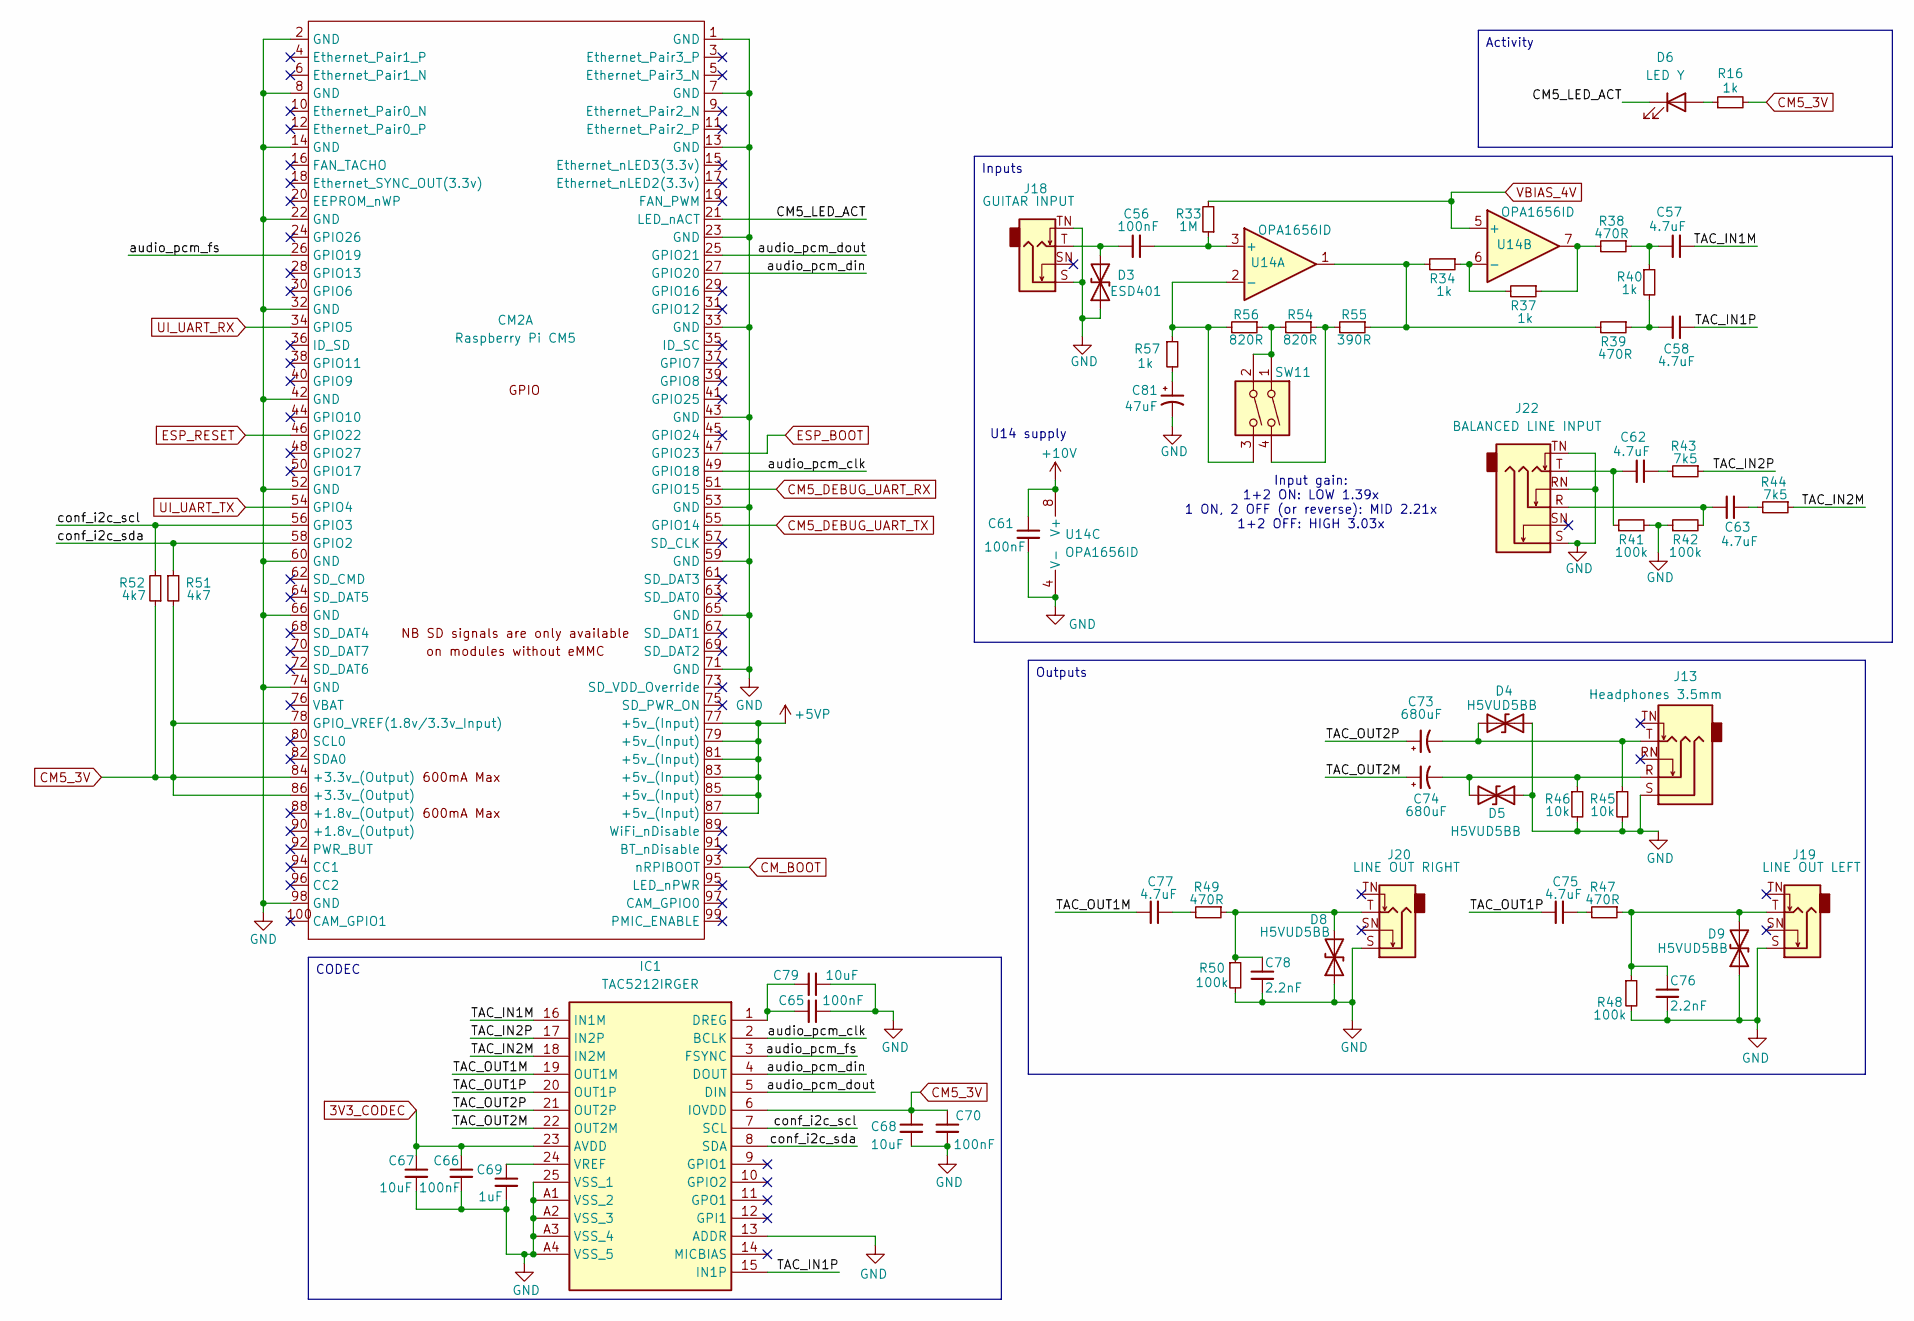
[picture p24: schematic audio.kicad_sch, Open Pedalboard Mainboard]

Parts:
C56: 100nF; C_Rect_L7.2mm_W3.5mm_P5.00mm_FKS2_FKP2_MKS2_MKP2
C57, C58, C62, C63: 4.7uF; C_1210_3225Metric_Pad1.33x2.70mm_HandSolder; Manufacturer part 16MF475KB23225; JLCPCB part C50394238
C61, C65, C66, C70: 100nF; C_0603_1608Metric; Manufacturer part CC0603KRX7R9BB104; JLCPCB part C14663
C67, C68, C79: 10uF; C_0805_2012Metric; Manufacturer part CL21A106KAYNNNE; JLCPCB part C15850
C69: 1uF; C_0805_2012Metric; Manufacturer part CL21B105KBFNNNE; JLCPCB part C28323
C73, C74: 680uF; CP_Radial_D8.0mm_P3.50mm; Manufacturer part EEU-FR1A681
C75, C77: 4.7uF; C_1206_3216Metric; Manufacturer part 1206B475K500NT; JLCPCB part C29823
C76, C78: 2.2nF; C_0603_1608Metric; Manufacturer part 0603B222K500NT; JLCPCB part C1604
C81: 47uF; CP_Radial_D6.3mm_P2.50mm; Manufacturer part ECA1EHG101
CM2: Raspberry Pi CM5; Raspberry-Pi-5-Compute-Module
D3: ESD401; Texas_DPY0002A_0.6x1mm_P0.65mm; Manufacturer part ESD401DPYR; JLCPCB part C1974752
D4, D5, D8, D9: H5VUD5BB; D_SOD-523; Manufacturer part H5VUD5BB; JLCPCB part C20615820
D6: LED Y; LED_0805_2012Metric; Manufacturer part KT-0805Y; JLCPCB part C2296
IC1: TAC5212IRGER; Manufacturer part TAC5212IRGER; JLCPCB part C44853694
J13: Headphones 3.5mm; Jack_3.5mm_CUI_SJ1-3525N_Horizontal; Manufacturer part SJ1-3525N
J18: GUITAR INPUT; Jack_6.35mm_Neutrik_NMJ4HCD2_Horizontal; Manufacturer part NMJ4HCD2
J19: LINE OUT LEFT; Jack_6.35mm_Neutrik_NMJ4HCD2_Horizontal; Manufacturer part NMJ4HCD2
J20: LINE OUT RIGHT; Jack_6.35mm_Neutrik_NMJ4HCD2_Horizontal; Manufacturer part NMJ4HCD2
J22: BALANCED LINE INPUT; Jack_6.35mm_Neutrik_NMJ6HCD2_Horizontal; Manufacturer part NMJ6HCD2
R16: 1k; R_0805_2012Metric; Manufacturer part 0805W8F1001T5E; JLCPCB part C17513
R33: 1M; R_0603_1608Metric; Manufacturer part 0603WAF1004T5E; JLCPCB part C22935
R34, R37, R40, R57: 1k; R_0603_1608Metric; Manufacturer part 0603WAF1001T5E; JLCPCB part C21190
R38, R39, R47, R49: 470R; R_0603_1608Metric; Manufacturer part 0603WAF4700T5E; JLCPCB part C23179
R41, R42, R48, R50: 100k; R_0603_1608Metric; Manufacturer part 0603WAF1003T5E; JLCPCB part C25803
R43, R44: 7k5; R_0603_1608Metric; Manufacturer part 0603WAF7501T5E; JLCPCB part C23234
R45, R46: 10k; R_0603_1608Metric; Manufacturer part 0603WAF1002T5E; JLCPCB part C25804
R51, R52: 4k7; R_0603_1608Metric; Manufacturer part 0603WAF4701T5E; JLCPCB part C23162
R54, R56: 820R; R_0603_1608Metric; Manufacturer part 0603WAF8200T5E; JLCPCB part C23253
R55: 390R; R_0603_1608Metric; Manufacturer part 0603WAF3900T5E; JLCPCB part C23151
SW11: EM-02-Q; SW_DIP_SPSTx02_Slide_6.7x6.64mm_W8.61mm_P2.54mm_LowProfile; Manufacturer part EM-02-Q; JLCPCB part C501539
U14: OPA1656ID; SOIC-8_3.9x4.9mm_P1.27mm; Manufacturer part OPA1656ID; JLCPCB part C1346368

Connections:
3V3_CODEC: C66.1, C67.1, IC1.23 (AVDD); also elsewhere on the board
+5VP: CM2.77 (+5v_(Input)), CM2.79 (+5v_(Input)), CM2.81 (+5v_(Input)), CM2.83 (+5v_(Input)), CM2.85 (+5v_(Input)), CM2.87 (+5v_(Input)); also elsewhere on the board
+10V: C61.1, U14.8 (V+); also elsewhere on the board
/Audio/CM5_LED_ACT: CM2.21 (LED_nACT), D6.1 (K)
/Audio/TAC_IN1M: C57.2, IC1.16 (IN1M)
/Audio/TAC_IN1P: C58.2, IC1.15 (IN1P)
/Audio/TAC_IN2M: IC1.18 (IN2M), R44.1
/Audio/TAC_IN2P: IC1.17 (IN2P), R43.1
/Audio/TAC_OUT1M: C77.1, IC1.19 (OUT1M)
/Audio/TAC_OUT1P: C75.1, IC1.20 (OUT1P)
/Audio/TAC_OUT2M: C74.1, IC1.22 (OUT2M)
/Audio/TAC_OUT2P: C73.1, IC1.21 (OUT2P)
/Audio/audio_pcm_clk: CM2.49 (GPIO18), IC1.2 (BCLK)
/Audio/audio_pcm_din: CM2.27 (GPIO20), IC1.4 (DOUT)
/Audio/audio_pcm_dout: CM2.25 (GPIO21), IC1.5 (DIN)
/Audio/audio_pcm_fs: CM2.26 (GPIO19), IC1.3 (FSYNC)
/Audio/conf_i2c_scl: CM2.56 (GPIO3), IC1.7 (SCL), R52.2
/Audio/conf_i2c_sda: CM2.58 (GPIO2), IC1.8 (SDA), R51.1
CM5_3V: C68.1, C70.1, CM2.78 (GPIO_VREF(1.8v/3.3v_Input)), CM2.84 (+3.3v_(Output)), CM2.86 (+3.3v_(Output)), IC1.6 (IOVDD), R16.2, R51.2, R52.1
CM5_DEBUG_UART_RX: CM2.51 (GPIO15); also elsewhere on the board
CM5_DEBUG_UART_TX: CM2.55 (GPIO14); also elsewhere on the board
CM_BOOT: CM2.93 (nRPIBOOT); also elsewhere on the board
ESP_BOOT: CM2.47 (GPIO23); also elsewhere on the board
ESP_RESET: CM2.46 (GPIO22); also elsewhere on the board
GND: C61.2, C65.2, C66.2, C67.2, C68.2, C69.2, C70.2, C76.2, C78.2, C79.2, C81.2, CM2.1 (GND), CM2.2 (GND), CM2.7 (GND), CM2.8 (GND), CM2.13 (GND), CM2.14 (GND), CM2.22 (GND), CM2.23 (GND), CM2.32 (GND), CM2.33 (GND), CM2.42 (GND), CM2.43 (GND), CM2.52 (GND), CM2.53 (GND), CM2.59 (GND), CM2.60 (GND), CM2.65 (GND), CM2.66 (GND), CM2.71 (GND), CM2.74 (GND), CM2.98 (GND), D3.1 (A1), D4.1 (A1), D5.1 (A1), D8.1 (A1), D9.1 (A1), IC1.13 (ADDR), IC1.25 (VSS_1), IC1.A1 (VSS_2), IC1.A2 (VSS_3), IC1.A3 (VSS_4), IC1.A4 (VSS_5), J13.S, J18.S, J18.TN, J19.S, J20.S, J22.RN, J22.S, J22.TN, R41.2, R42.1, R45.2, R46.2, R48.2, R50.2, U14.4 (V-); also elsewhere on the board
unnamed: C57.1, R38.1, R40.1
unnamed: C58.1, R39.1, R40.2
unnamed: C62.1, J22.T, R41.1
unnamed: C62.2, R43.2
unnamed: C63.1, J22.R, R42.2
unnamed: C63.2, R44.2
unnamed: C75.2, R47.2
unnamed: C77.2, R49.2
unnamed: C81.1, R57.2
unnamed: C56.1, D3.2 (A2), J18.T
unnamed: C73.2, D4.2 (A2), J13.T, R45.1
unnamed: C74.2, D5.2 (A2), J13.R, R46.1
unnamed: D6.2 (A), R16.1
unnamed: C78.1, D8.2 (A2), J20.T, R49.1, R50.1
unnamed: C76.1, D9.2 (A2), J19.T, R47.1, R48.1
unnamed: C65.1, C79.1, IC1.1 (DREG)
unnamed: C69.1, IC1.24 (VREF)
unnamed: R34.2, R39.2, R55.1, U14.1
unnamed: R37.1, R38.2, U14.7
unnamed: R54.1, R55.2, SW11.4
unnamed: R54.2, R56.1, SW11.1, SW11.2
unnamed: C56.2, R33.1, U14.3 (+)
unnamed: R56.2, R57.1, SW11.3, U14.2 (-)
unnamed: R34.1, R37.2, U14.6 (-)
UI_UART_RX: CM2.34 (GPIO5); also elsewhere on the board
UI_UART_TX: CM2.54 (GPIO4); also elsewhere on the board
VBIAS_4V: R33.2, U14.5 (+); also elsewhere on the board

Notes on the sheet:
Input gain: 1+2 ON: LOW 1.39x 1 ON, 2 OFF (or reverse): MID 2.21x 1+2 OFF: HIGH 3.03x
U14 supply
Inputs
Activity
CODEC
Outputs

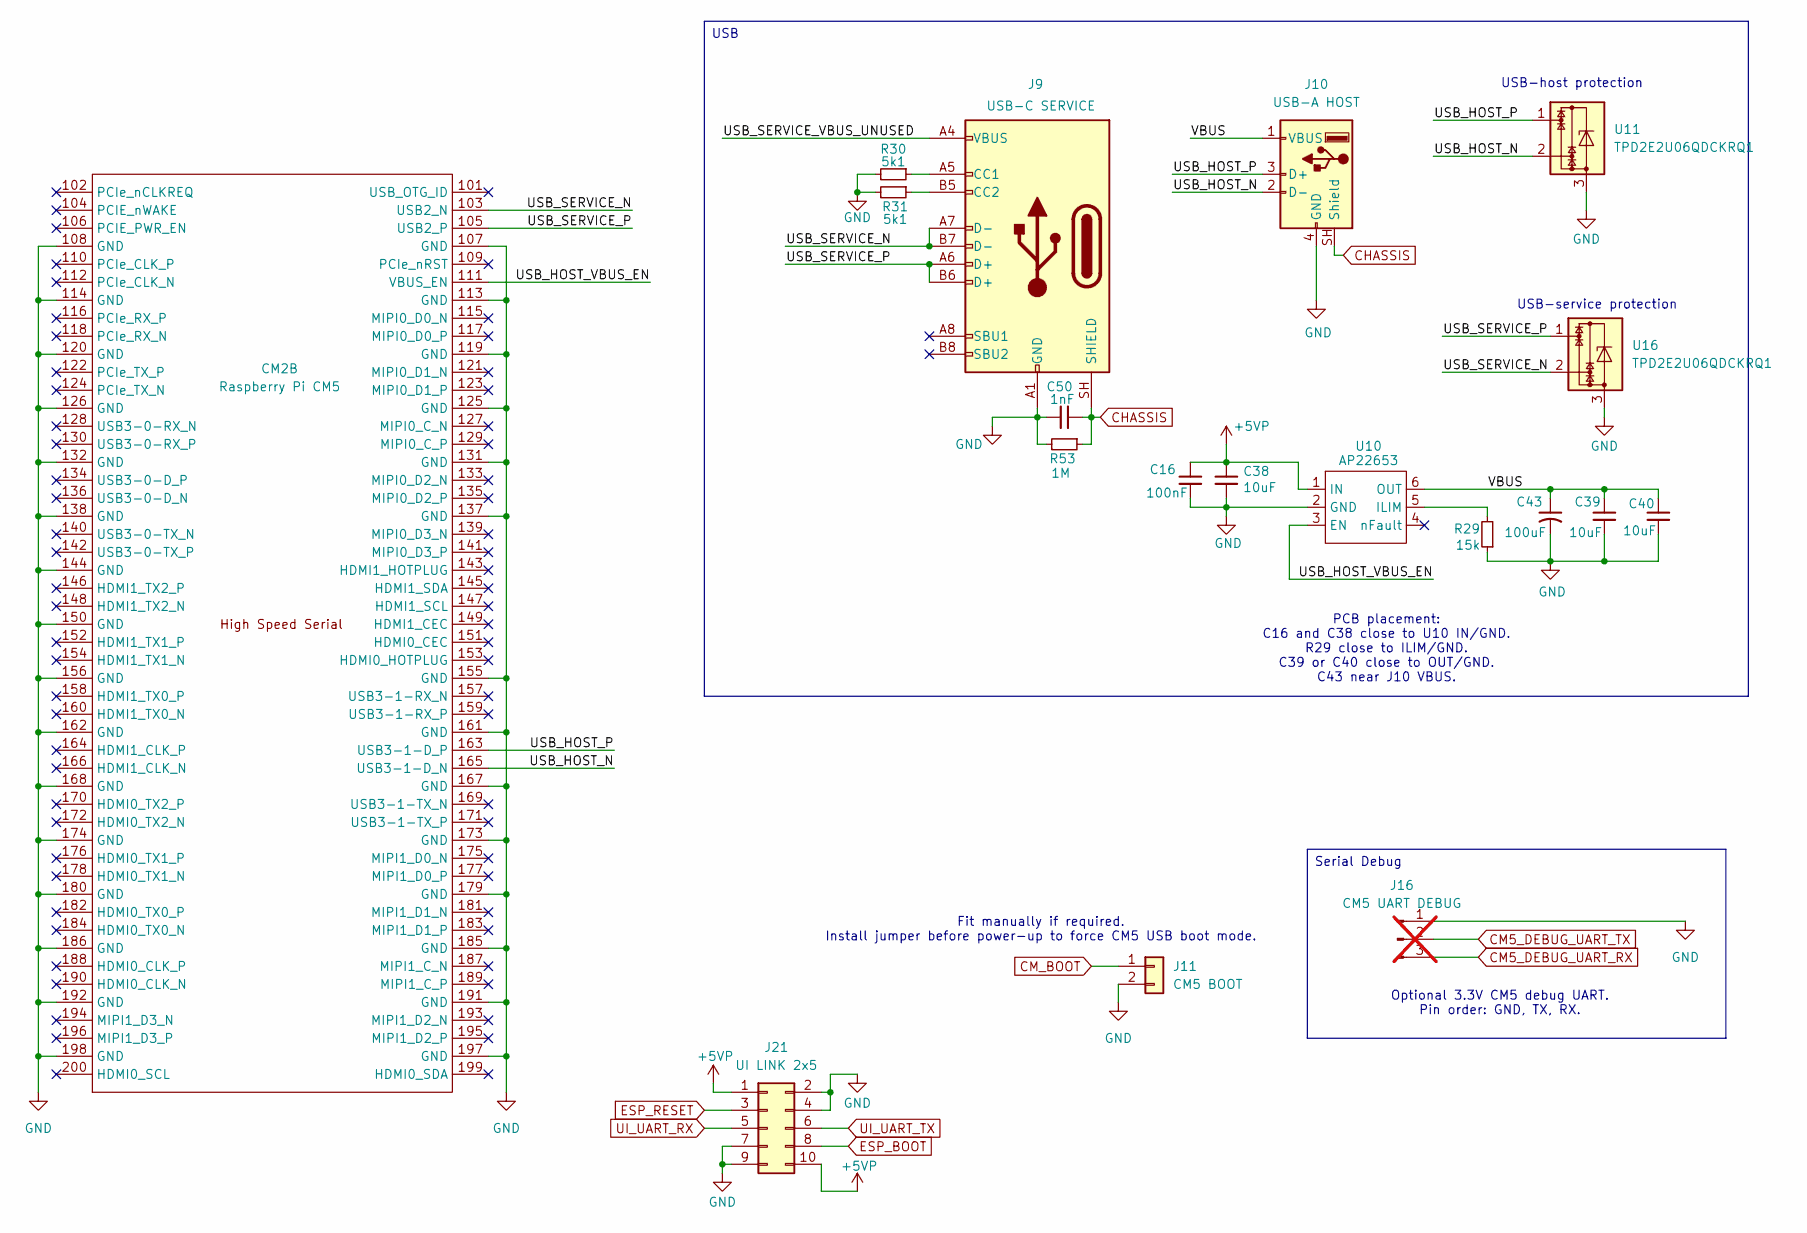
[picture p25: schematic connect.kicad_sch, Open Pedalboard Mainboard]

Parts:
C16: 100nF; C_0603_1608Metric; Manufacturer part CC0603KRX7R9BB104; JLCPCB part C14663
C38, C39, C40: 10uF; C_0805_2012Metric; Manufacturer part CL21A106KAYNNNE; JLCPCB part C15850
C43: 100uF; CP_Radial_D8.0mm_P3.50mm; Manufacturer part RR71C101MDN1
C50: 1nF; C_1206_3216Metric; Manufacturer part GRM31C5C3A102JWA3L; JLCPCB part C521240
CM2: Raspberry Pi CM5; Raspberry-Pi-5-Compute-Module
J9: USB-C SERVICE; USB_C_Receptacle_GCT_USB4105-xx-A_16P_TopMnt_Horizontal; Manufacturer part USB4105-GF-A-120; JLCPCB part C5184243
J10: USB-A HOST; USB_A_Molex_67643_Horizontal; Manufacturer part 67643-3910
J11: CM5 BOOT; PinHeader_1x02_P2.54mm_Vertical
J16: CM5 UART DEBUG; PinHeader_1x03_P2.54mm_Vertical; not fitted
J21: UI LINK 2x5; J_Wurth_WR-BHD_61201021621; Manufacturer part 61201021621
R29: 15k; R_0805_2012Metric; Manufacturer part 0805W8F1502T5E; JLCPCB part C17475
R30, R31: 5k1; R_0402_1005Metric; Manufacturer part 0402WGF5101TCE; JLCPCB part C25905
R53: 1M; R_0603_1608Metric; Manufacturer part 0603WAF1004T5E; JLCPCB part C22935
U10: AP22653; SOT-23-6; Manufacturer part AP22653W6-7; JLCPCB part C2158037
U11, U16: TPD2E2U06QDCKRQ1; SOT-323_SC-70; Manufacturer part TPD2E2U06QDCKRQ1; JLCPCB part C915089

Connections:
+5VP: C16.1, C38.1, J21.1, J21.10, U10.1 (IN); also elsewhere on the board
/Connectivity/USB_HOST_N: CM2.165 (USB3-1-D_N), J10.2 (D-), U11.2
/Connectivity/USB_HOST_P: CM2.163 (USB3-1-D_P), J10.3 (D+), U11.1
/Connectivity/USB_HOST_VBUS_EN: CM2.111 (VBUS_EN), U10.3 (EN)
/Connectivity/USB_SERVICE_N: CM2.103 (USB2_N), J9.A7 (D-), J9.B7 (D-), U16.2
/Connectivity/USB_SERVICE_P: CM2.105 (USB2_P), J9.A6 (D+), J9.B6 (D+), U16.1
/Connectivity/USB_SERVICE_VBUS_UNUSED: J9.A4 (VBUS), J9.A9 (VBUS), J9.B4 (VBUS), J9.B9 (VBUS)
/Connectivity/VBUS: C39.1, C40.1, C43.1, J10.1 (VBUS), U10.6 (OUT)
CHASSIS: C50.2, J9.SH (SHIELD), J10.SH (Shield), R53.1
CM5_DEBUG_UART_RX: J16.3; also elsewhere on the board
CM5_DEBUG_UART_TX: J16.2; also elsewhere on the board
CM_BOOT: J11.1; also elsewhere on the board
ESP_BOOT: J21.8; also elsewhere on the board
ESP_RESET: J21.3; also elsewhere on the board
GND: C16.2, C38.2, C39.2, C40.2, C43.2, C50.1, CM2.107 (GND), CM2.108 (GND), CM2.113 (GND), CM2.114 (GND), CM2.119 (GND), CM2.120 (GND), CM2.125 (GND), CM2.126 (GND), CM2.131 (GND), CM2.132 (GND), CM2.137 (GND), CM2.138 (GND), CM2.144 (GND), CM2.150 (GND), CM2.155 (GND), CM2.156 (GND), CM2.161 (GND), CM2.162 (GND), CM2.167 (GND), CM2.168 (GND), CM2.173 (GND), CM2.174 (GND), CM2.179 (GND), CM2.180 (GND), CM2.185 (GND), CM2.186 (GND), CM2.191 (GND), CM2.192 (GND), CM2.197 (GND), CM2.198 (GND), J9.A1 (GND), J9.A12 (GND), J9.B1 (GND), J9.B12 (GND), J10.4 (GND), J11.2, J16.1, J21.2, J21.4, J21.7, J21.9, R29.1, R30.2, R31.2, R53.2, U10.2 (GND), U11.3, U16.3; also elsewhere on the board
unnamed: J9.A5 (CC1), R30.1
unnamed: J9.B5 (CC2), R31.1
unnamed: R29.2, U10.5 (ILIM)
UI_UART_RX: J21.5; also elsewhere on the board
UI_UART_TX: J21.6; also elsewhere on the board

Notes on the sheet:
Optional 3.3V CM5 debug UART. Pin order: GND, TX, RX.
PCB placement: C16 and C38 close to U10 IN/GND. R29 close to ILIM/GND. C39 or C40 close to OUT/GND. C43 near J10 VBUS.
USB-host protection
USB-service protection
Fit manually if required. Install jumper before power-up to force CM5 USB boot mode.
USB
Serial Debug

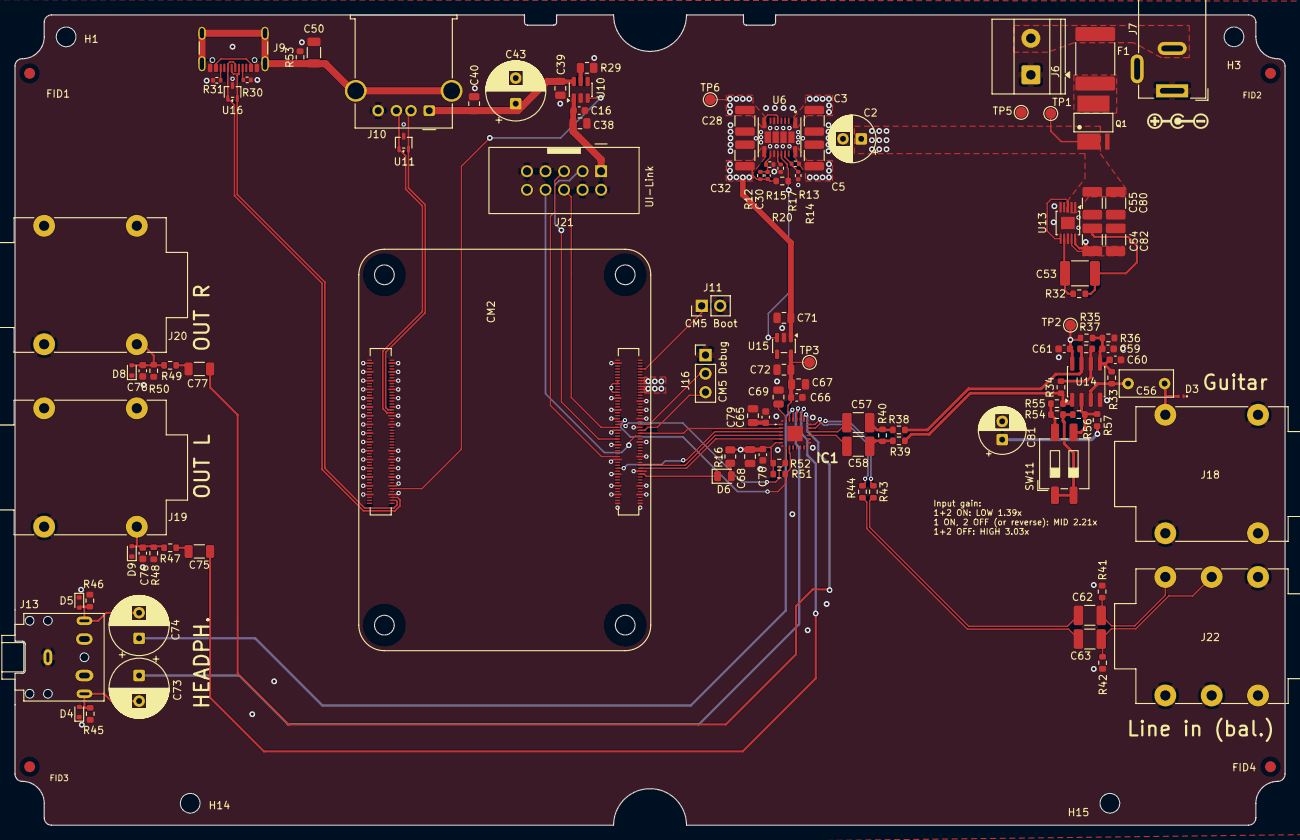
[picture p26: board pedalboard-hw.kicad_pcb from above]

Board: 4 copper layers, 174.0 x 111.0 mm, 120 parts (0 on the bottom side), 71 nets.

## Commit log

2026-09-02 Initial integrated audio project snapshot
    [10103594-0001LF--3DModel-STEP-269445.STEP, 3-D NMJ6HCD2.stp, 694106301002 (rev1).stp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]
2026-09-02 updated docs from chatgpt discussions.
    [audio.kicad_sch]
2026-09-02 added datasheets - wired up line level input components.
    [audio.kicad_sch]
2026-09-04 Supply work on TAC5212
    [audio.kicad_sch, psu.kicad_sch]
2026-09-10 Checkpoint before CM5 connectivity migration
    [RPA0010A.stp, audio.kicad_sch, connect.kicad_sch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]
2026-09-11 Changed to CM5, removed unnecessary USB chips, Changing RP2024 to STM32.
    [audio.kicad_sch, connect.kicad_sch, pedalboard-hw.kicad_sch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]
2026-09-11 Updated to use STM32
    [audio.kicad_sch, connect.kicad_sch, leds.kicad_sch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]
2026-09-11 updated lcd connectors
    [pico.kicad_sch]
2026-09-11 small fixes
    [pico.kicad_sch]
2026-09-11 Update display and 3.3V decisions
2026-09-11 Update display and 3.3V design notes
2026-09-11 Update project README for current hardware
2026-09-11 add more cap
    [audio.kicad_sch]
2026-09-11 updated cap
    [audio.kicad_sch]
2026-09-11 changd diode.
    [audio.kicad_sch]
2026-09-12 small edits
    [leds.kicad_sch, pico.kicad_sch]
2026-09-12 some stuff
    [TAC5212IRGER.stp, audio.kicad_sch]
2026-09-12 a few edits
    [audio.kicad_sch, connect.kicad_sch, pico.kicad_sch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]
2026-09-12 fixed warnings.
    [audio.kicad_sch, connect.kicad_sch, leds.kicad_sch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]
2026-09-12 Standardize values.
    [audio.kicad_sch, connect.kicad_sch, pico.kicad_sch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]
2026-09-12 edited metadata
    [audio.kicad_sch, psu.kicad_sch]
2026-09-12 more meta
    [audio.kicad_sch, connect.kicad_sch, leds.kicad_sch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]
2026-09-12 added TLVM13660
    [RDL0020A.stp]
2026-09-12 Changed 5V chip to TLVM13660
    [psu.kicad_sch]
2026-09-13 U10 components metadata
    [connect.kicad_sch]
2026-09-18 Updated various metadata
    [audio.kicad_sch, connect.kicad_sch, leds.kicad_sch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]
2026-09-18 changed to lt3042
    [psu.kicad_sch]
2026-09-18 update components
    [psu.kicad_sch]
2026-09-18 more edits
    [psu.kicad_sch]
2026-09-21 Moving to seperate ui board using ESP32
    [J_Wurth_WR-BHD_61201021621.step, audio.kicad_sch, connect.kicad_sch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]
2026-09-21 update 3d model of J21
    [connect.kicad_sch]
2026-09-21 update psu
    [audio.kicad_sch, psu.kicad_sch]
2026-09-21 added test points
    [audio.kicad_sch, psu.kicad_sch]
2026-09-21 small edit
    [psu.kicad_sch]
2026-09-21 initital pcb work
    [connect.kicad_sch, pedalboard-hw.kicad_pcb]
2026-09-23 initial placement fiddling
    [audio.kicad_sch, pedalboard-hw.kicad_pcb, pedalboard-hw.kicad_sch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]
2026-09-25 components placed.
    [audio.kicad_sch, pedalboard-hw.kicad_pcb, pedalboard-hw.kicad_sch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]
2026-09-25 fixed something.
    [pedalboard-hw.kicad_pcb]
2026-09-27 more via
    [pedalboard-hw.kicad_pcb]
2026-09-27 tlvm vias done.
    [pedalboard-hw.kicad_pcb]
2026-09-28 Add temporary README board render workflow
2026-09-28 Add temporary KiCad README render config
2026-09-28 Use KiCad 3D renderer for README preview
2026-09-28 Clear schematic DNP flags for C2 and J7 preview
2026-09-28 Revise README with comprehensive project details
    Expanded the README to include detailed project goals, system architecture, audio architecture, power architecture, and current status. Updated project description and added sections on design goals,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
2026-09-28 5V power to CM5
    [connect.kicad_sch, pedalboard-hw.kicad_pcb]
2026-09-28 grounding CM5
    [pedalboard-hw.kicad_pcb]
2026-09-29 more psu
    [connect.kicad_sch, pedalboard-hw.kicad_pcb, psu.kicad_sch]
2026-09-30 Automate README board render on PCB changes
2026-09-30 opamp incl power routed
    [audio.kicad_sch, pedalboard-hw.kicad_pcb, psu.kicad_sch]
2026-09-30 Update README board render
2026-09-30 Routing IC1
    [pedalboard-hw.kicad_pcb]
2026-10-01 more routing.
    [pedalboard-hw.kicad_pcb]
2026-10-01 yet more routing.
    [pedalboard-hw.kicad_pcb]
2026-10-02 bit more routing.
    [pedalboard-hw.kicad_pcb]
2026-10-02 Fiddles. Moved J6
    [pedalboard-hw.kicad_pcb, psu.kicad_sch]
2026-10-02 various fixes.
    [D-NMJ4HCD2.stp, audio.kicad_sch, connect.kicad_sch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]
2026-10-02 Setting up JLCPCB population variant.
    [audio.kicad_sch, connect.kicad_sch, pedalboard-hw.kicad_pcb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]
2026-10-03 Updated parts to available jlcpcb parts.
    [audio.kicad_sch, connect.kicad_sch, pedalboard-hw.kicad_pcb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]

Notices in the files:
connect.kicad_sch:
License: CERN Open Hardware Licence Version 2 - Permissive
